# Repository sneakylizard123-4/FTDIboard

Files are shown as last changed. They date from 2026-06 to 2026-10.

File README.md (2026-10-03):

# FTDIboard

FTDIboard is a small USB-to-UART interface that uses the FT232RL and a switchable 3.3V/5V logic rail.

[Finished V1 board](proof/V1/image/IMG_20260908_173817_623.jpg)

---

## Key Features

- FT232RL USB-to-UART bridge
- Switchable 3.3V / 5V logic levels  
- ESP-style auto-reset
- USB ESD protection
- Resettable Fuse (PPTC): 600mA on VBUS 
- Fuse (not resettable): 2.5A fast fuse
- Lots of LEDs
- 75×50mm, 4-layer PCB
- M3 mounting holes
- 2.54mm standard headers

---

## Bill of Materials

| References | Qty | Value | Footprint |
|---|-----|---|---|
| U3 | 1 | FT232RL | SSOP-28 |
| U2 | 1 | TLV75733PDBV | SOT-23-5 |
| U1 | 1 | USBLC6-2SC6 | SOT-23-6 |
| C1 C4 C5 C7 C8 C10 | 6 | 100nF | 0805 |
| C6 C9 | 2 | 4.7uF | 0805 |
| C2 | 1 | 10uF | 0805 |
| C3 | 1 | 22uF | 0805 |
| R4 R10 R12 R13 R14 R15 R16 R17 R18 R19 R20 R21 R22 R23 R24 R25 | 16 | 10k | 0805 |
| R7 R8 R9 R11 | 4 | 1k | 0805 |
| R3 | 1 | 100k | 0805 |
| R1 R2 | 2 | 5.1k | 0805 |
| R5 R6 | 2 | 33R | 0805 |
| Q2 Q3 | 2 | BC817 | SOT-23 |
| Q1 | 1 | AO3401A | SOT-23 |
| D1 D2 D3 D4 D5 D6 D7 D8 D9 D10 D11 D12 D13 | 13 | LED | 0805 LED |
| J3 | 1 | Conn_01x04 | 1x4 Header 2.54mm |
| J2 | 1 | Conn_01x07 | 1x7 Header 2.54mm |
| J1 | 1 | USB_C_Receptacle_USB2.0_14P | USB-C Receptacle |
| F1 | 1 | 600mA hold, 1.2A trip | Disc 5.1mm |
| F2 | 1 | 2.5A trip | 0603 |
| SW1 | 1 | SW_SPDT_321 | SPDT Slide switch |

*Full BOM available in BOM.csv*

## Usage

1. Connect via USB
2. Install FTDI VCP drivers if needed
3. Select serial port in your IDE
4. Have fun

---

## Images

### PCB Layout
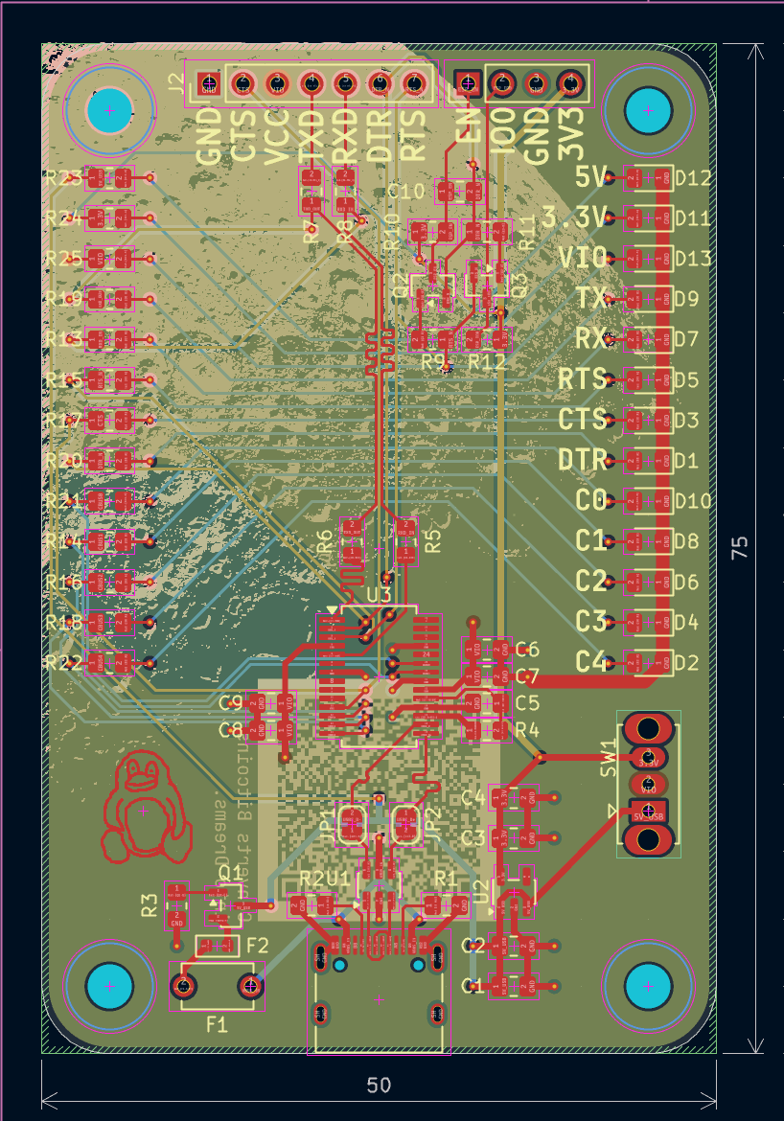
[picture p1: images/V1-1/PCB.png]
PCB


### Schematic
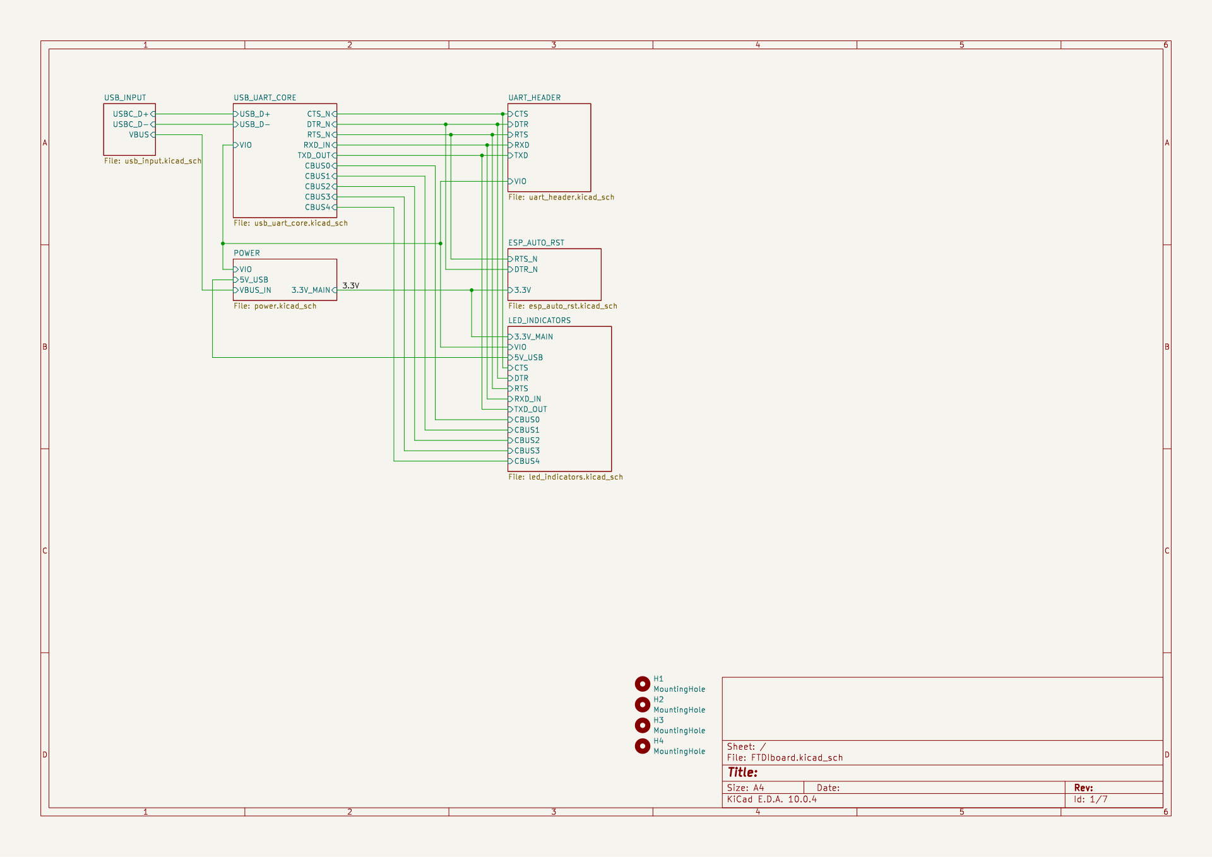
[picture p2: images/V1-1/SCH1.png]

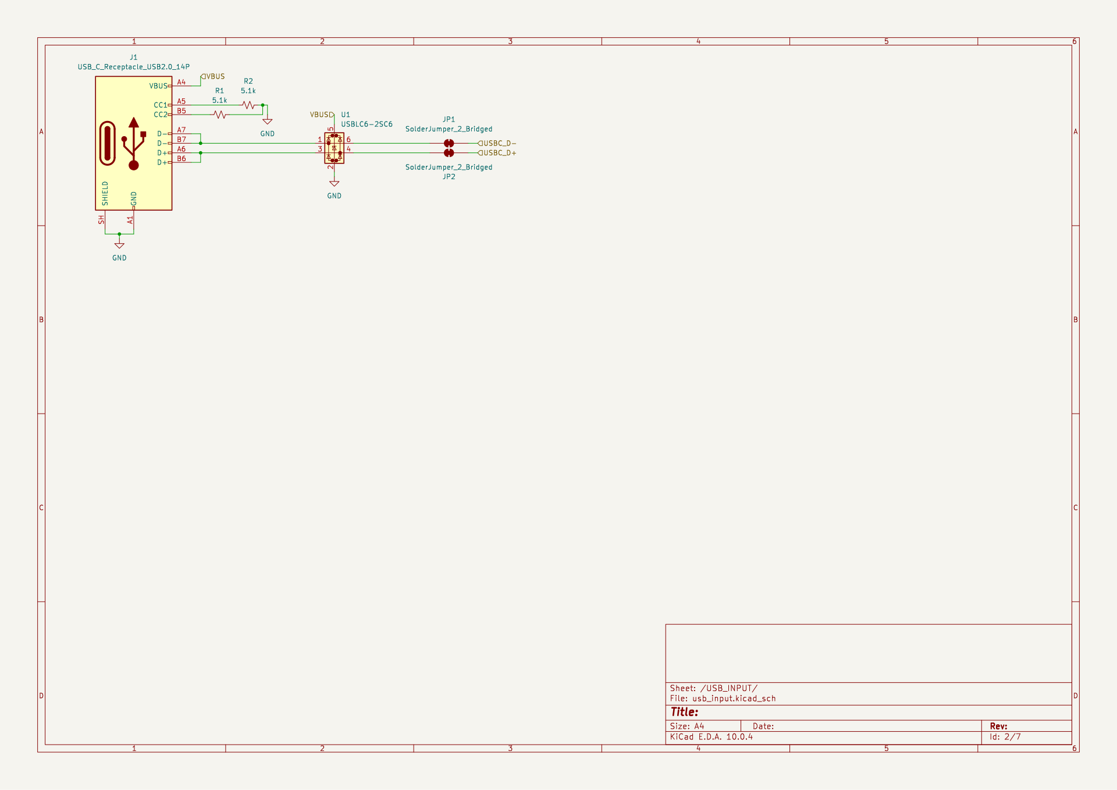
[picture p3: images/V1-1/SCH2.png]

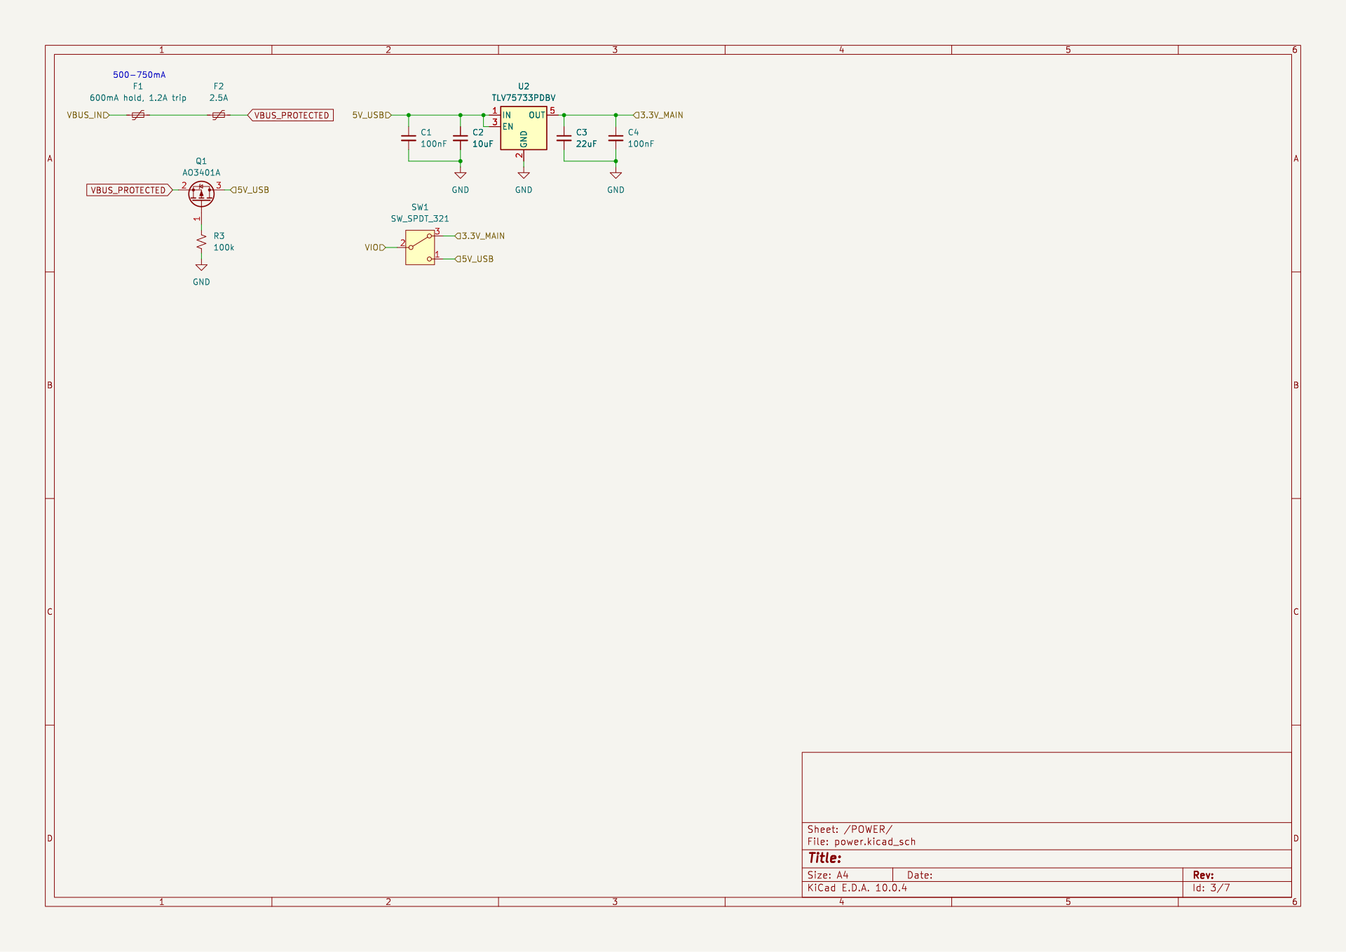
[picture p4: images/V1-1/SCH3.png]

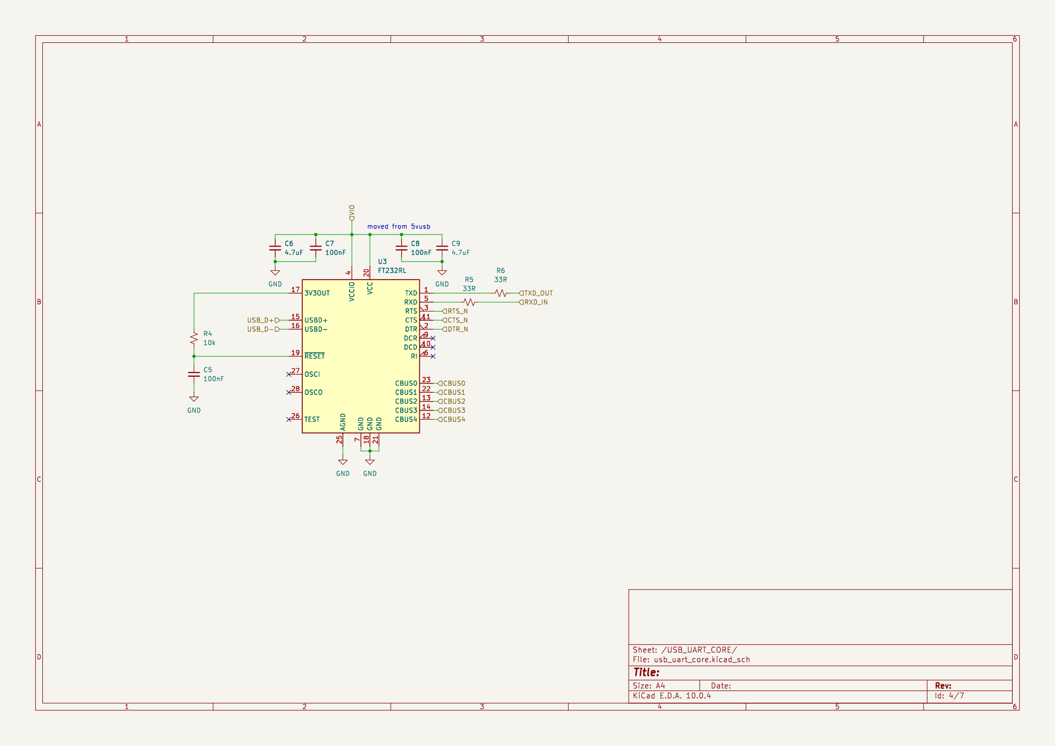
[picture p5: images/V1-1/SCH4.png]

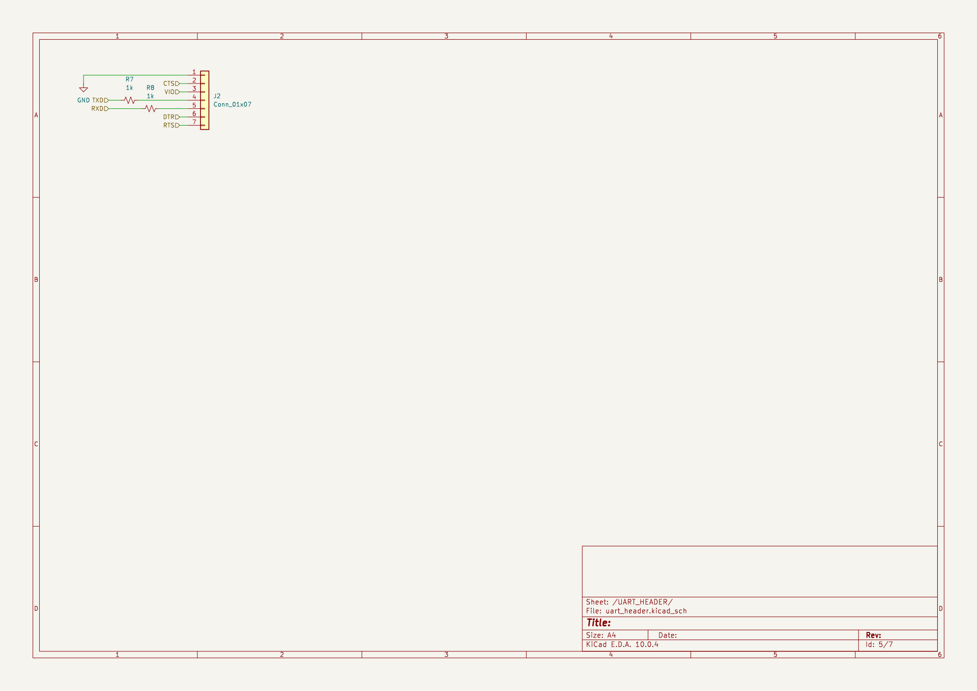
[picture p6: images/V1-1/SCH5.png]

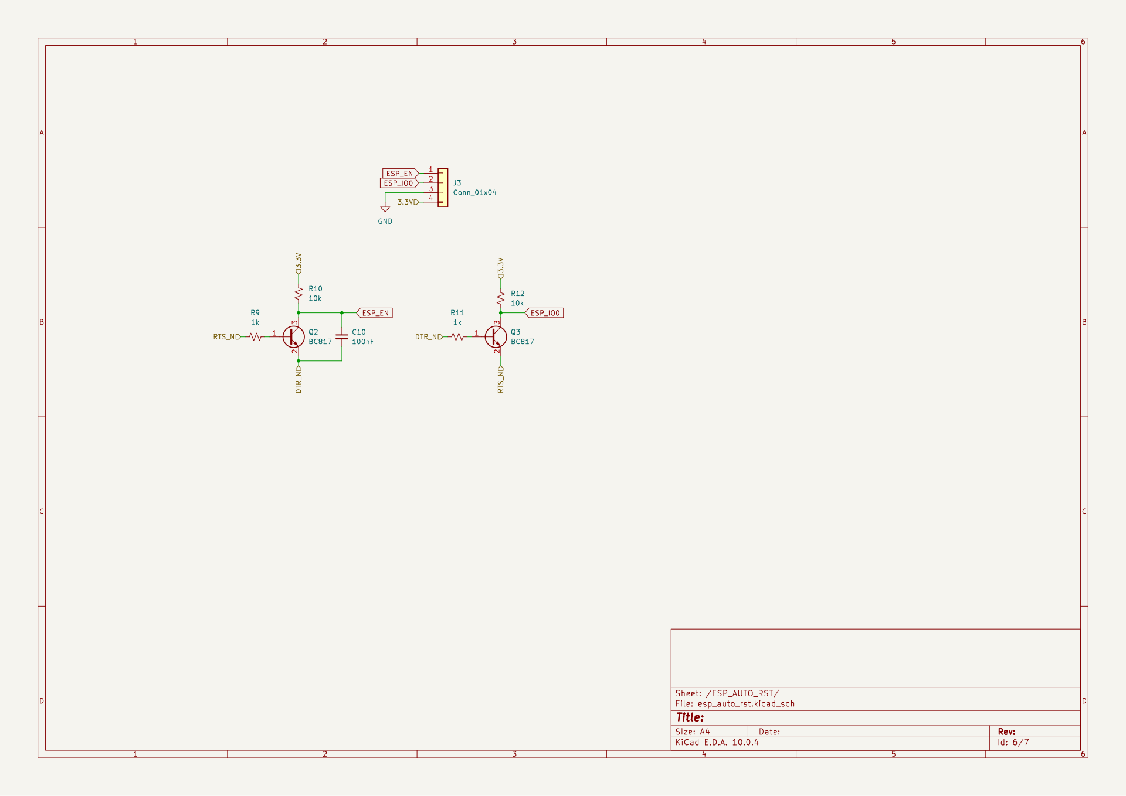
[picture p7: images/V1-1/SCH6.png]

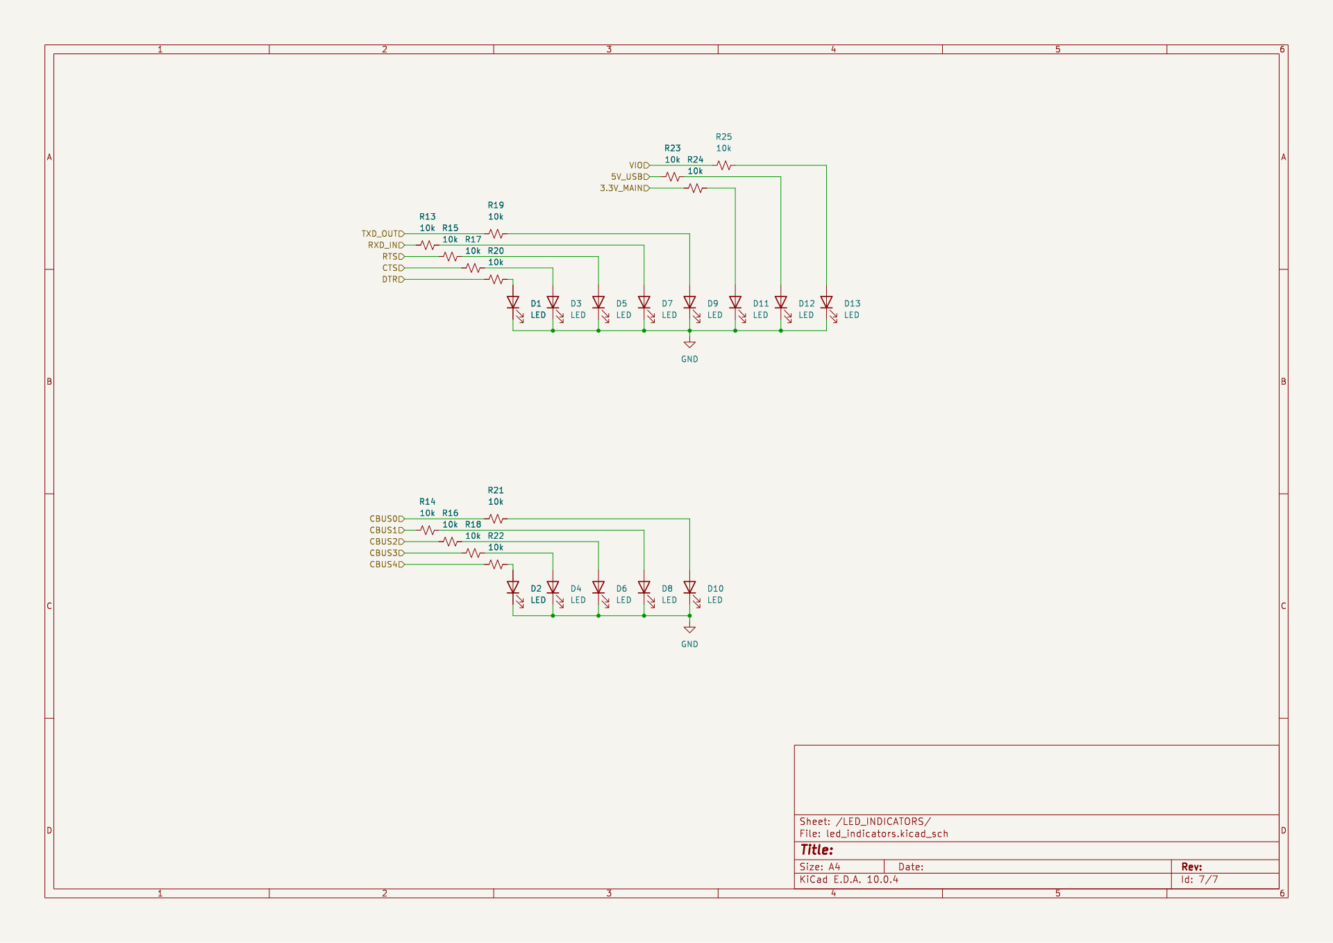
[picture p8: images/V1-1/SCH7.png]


### 3D Model
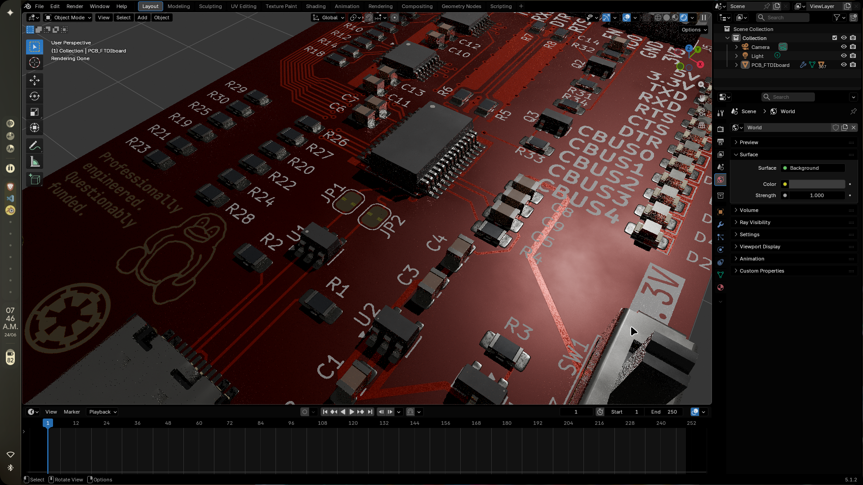
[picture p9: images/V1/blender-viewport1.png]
3D View

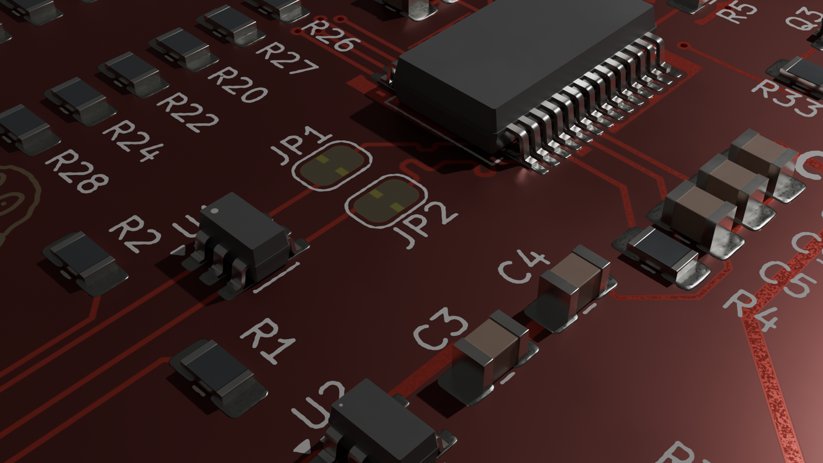
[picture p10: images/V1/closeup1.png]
Closeup


---

## Testing

v1.1 board built and tested, self-loopback passes clean. the two v1.0 bugbear fixes
(auto-reset latch, VCCIO following the switch) are confirmed gone in this revision.

- v1.1 build + test proof: `proof/V1-1/PROOF.md`
- v1.0 electrical soundness proof: `proof/V1/PROOF.md`

---

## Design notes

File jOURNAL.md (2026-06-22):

---
title: "FTDI Board"
author: pn2222a
descrriptioni: "FTDI USB board based on FT232RL chip"
created_at: "2026-06-21T02:59:14Z"
---

# June 20: finished board

finished the board.
added moon silkscreen and some more easter eggs, even though it will probably be only me that uses it
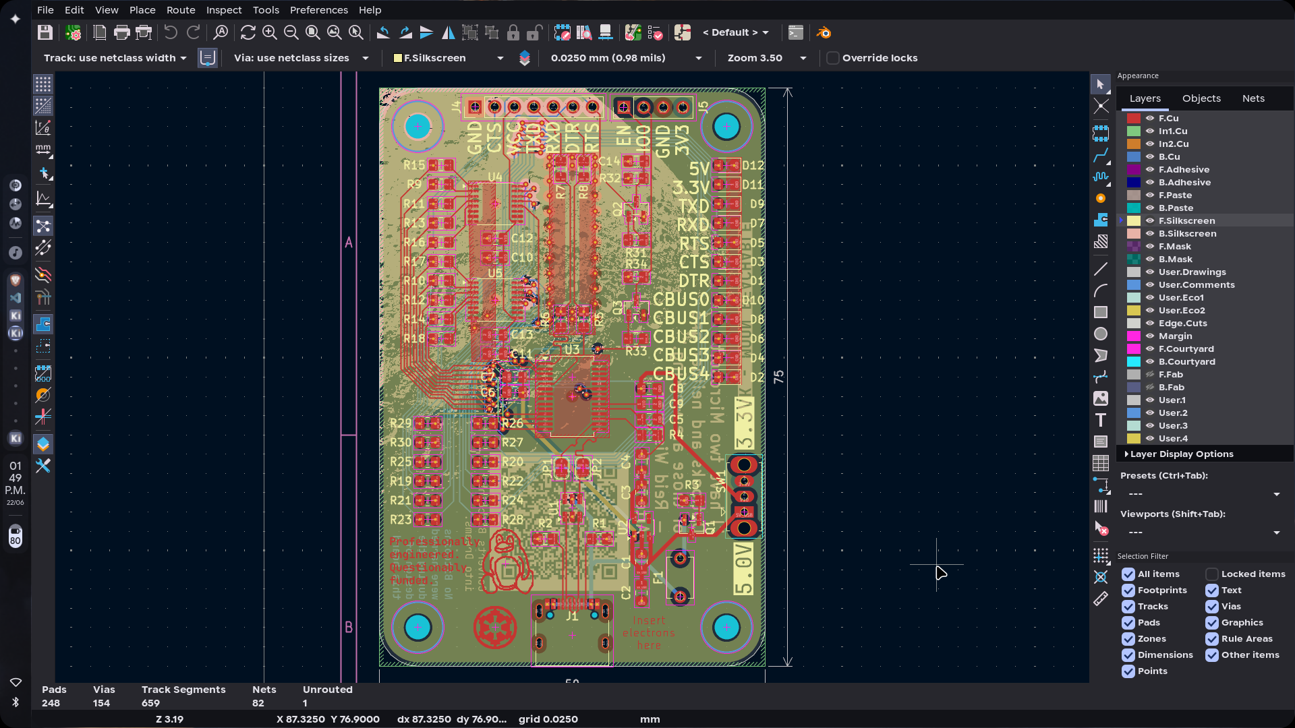
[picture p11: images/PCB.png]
pcb


**Total time spent: 6 hours**

# June 21: polishing repo
adding images from kicad and will start blendering soon for some cool renders
i need to learn how to make the renders faster.
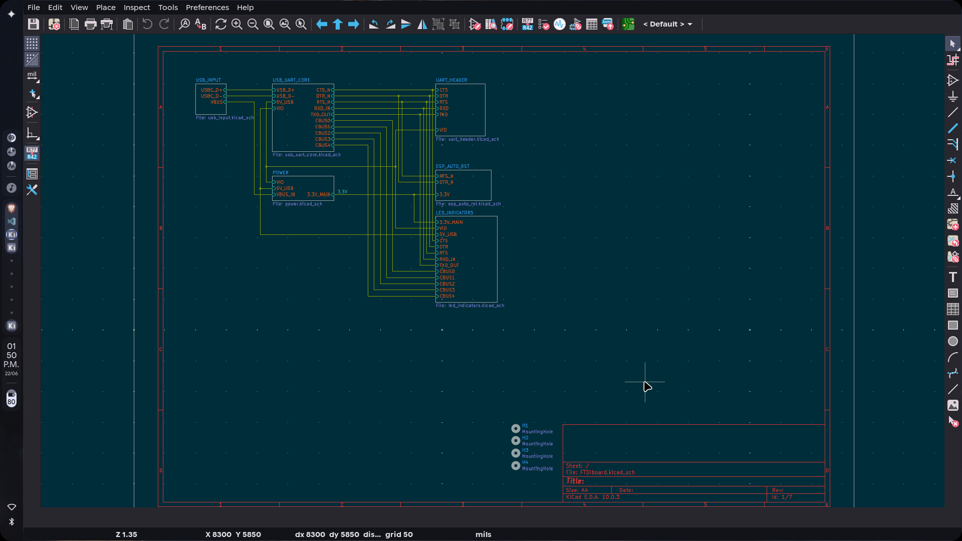
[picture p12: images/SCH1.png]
sch


**Total time spent: 2 hours**

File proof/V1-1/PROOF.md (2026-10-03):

# v1.1 Build + Testing Proof

Build/test date: September 21, 2026. This is the v1.1 revision (no ULN2003s, second
fuse, 13 LEDs, full reroute from the September 1 redesign).

## Build

- PCBs assembled, powered up, nothing released the magic smoke.
- Fuse footprint bridged with tweezers (same as v1.0 - never bothered fitting
  the PPTC, just shorted it). On camera: `video/VID_20260921_184839.mp4`.
- All LEDs lit and stayed lit.

## Testing

- Re-ran the proof kit from v1.0 (self-loopback, paced ESP32 traffic,
  sustained-load stress).
- The two v1.0 issues are gone in this revision:
  - auto-reset stage no longer latches (was a bodge wire on v1.0)
  - VCCIO rail follows the switch properly, no bodge wire needed (was 3.3V
    even in 5V mode on v1.0)
- Test script running on camera: `video/VID_20260921_190001.mp4`.
- Full self-loopback passes clean.

## Media

| File | What it shows |
|---|---|
| `video/VID_20260921_184839.mp4` | bridging the fuse with tweezers, LEDs lighting up |
| `video/VID_20260921_190001.mp4` | test script running / self-loopback passing |
| `image/IMG_20260921_185508_130.jpg` | built v1.1 board |
| `image/IMG_20260921_185721_778.jpg` | built v1.1 board |

See `proof/V1/PROOF.md` for the original v1.0 electrical soundness proof.

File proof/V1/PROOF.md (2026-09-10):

# Custom FT232RL Board - Interconnection Proof

Date of test: September 2, 2026 - All tests on `/dev/ttyUSB0` (custom board, bus 3-1, id `0403:6001`)

## Bottom line
The custom FT232RL USB-UART board is **electrically sound** (Yay!). Intermittent bit flips seen in
sustained transfers to the ESP32 are caused by a **marginal hookup wire / connection on the
board->ESP32 path, not by the board** and not by the ESP32.

---

## 1. Board integrity - pure self-loopback (decisive)
Board TX jumpered to RX, ESP32 fully disconnected.

- 500 x 512-byte pseudo-random blocks @ 115200 baud, back-to-back
- **Result: 500/500 PASS, 0 bad bytes, 8.7 kB/s**

```
=== SELF-LOOPBACK RESULT ===
passed : 500/500
failed : 0
bad bytes total: 0
VERDICT: PASS - BOARD TX/RX DRIVER INTEGRITY OK
```
Script: `board_selfloopback.py`

512 bytes was chosen because it is the exact block size that triggers bit flips *through the
ESP32*; the board alone never flips a bit. This rules out the board's TX/RX driver.

## 2. Direct PC loopback (board + cable + PC port all proven)
Board TX/RX jumpered, driven purely by the host PC.

- 100 x 32-byte pseudo-random chunks @ 115200
- **Result: 100/100 echoed correctly, 0 errors**

## 3. Integration with ESP32 (Adafruit HUZZAH32, UART2 RX=19/TX=21)
- Light traffic (16-byte frames, 50 ms gap): **20/20 PASS**
- Short frames (<=64 B, even 100 uss gap): **100% PASS**
- Single bytes: **300/300 PASS**

The board reliably talks to the ESP32 for normal, paced UART traffic.

## 4. The fault we chased (for completeness)
Under sustained ~512-byte back-to-back frames to the ESP32, ~40% of blocks had **exactly one
bad byte with 1-2 single-bit flips** (no frameshift, no desync - e.g. `0x47->0x07`). Downstream
checks proved:
- Not an ESP32 buffer overflow (enlarged RX buffer -> no change).
- Corruption originates on the **board TX -> ESP RX wire**, since the ESP32 mirrored exactly what
  arrived (board echo and ESP mirror were always bad together).
- The board alone does not produce it (see sec.1).

So the flips exist only when the board drives the wire to the ESP32 -> **marginal hookup wire /
contact**, consistent with the earlier-measured ~12 ohm twisted pair.

## Media

Videos from GoPro camera. Originals are 4-5K and several GB
each, so the repo only contains compressed 1280px or 960px previews in `video/compressed/`.

## Files
- Board self-loopback proof: `board_selfloopback.py`
- 1 MB stress benchmark: `customboard_bench.py` (fails via wire, see sec.4)
- Diagnostics: `diag_rate.py`, `diag_txrx.py`, `diag_bits.py`
- ESP32 echo firmware: `esp32_echo` (UART2 RX=19/TX=21, echoes + mirrors to UART0)

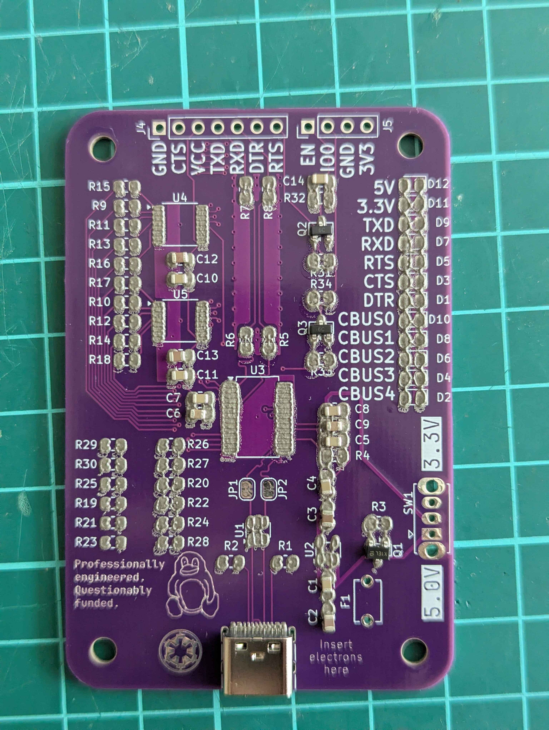
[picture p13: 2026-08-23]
images/V1/paste_5.jpg

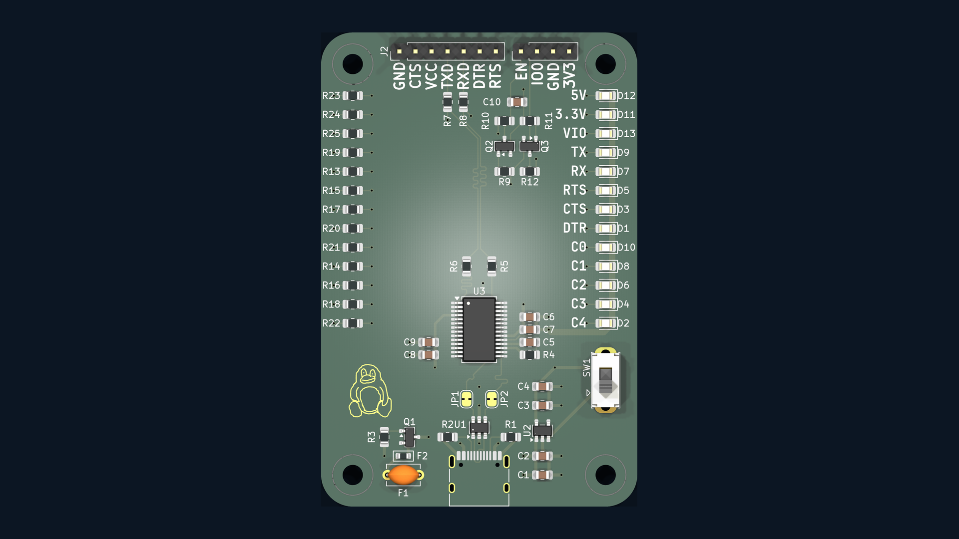
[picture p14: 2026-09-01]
images/V1-1/PCB-Render.png

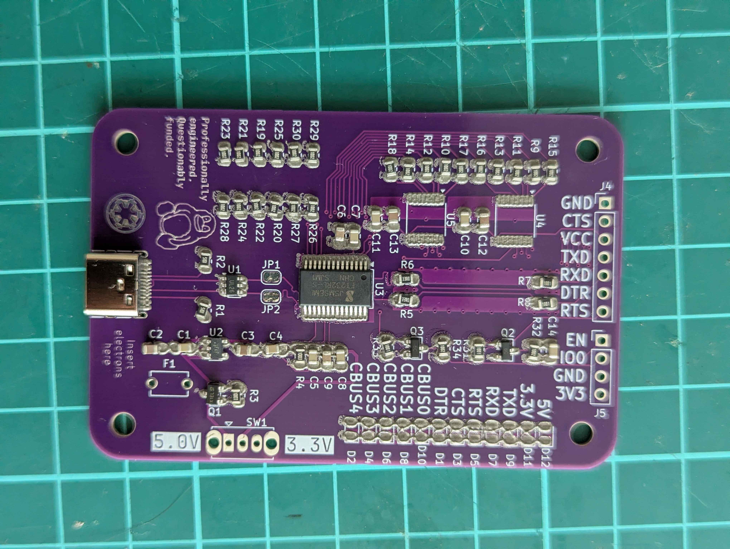
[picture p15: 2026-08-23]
images/V1/paste_10.jpg

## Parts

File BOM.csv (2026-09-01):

Component | Qty | LCSC Part # | Unit Price | Line Total | Buy
FT232RL | 1 | C8690 | $6.1561 | $6.16 | https://www.lcsc.com/product-detail/_C8690.html
TLV75733PDBV | 1 | C485517 | $0.1819 | $0.18 | https://www.lcsc.com/product-detail/_C485517.html
USBLC6-2SC6 | 1 | C7519 | $0.0896 | $0.09 | https://www.lcsc.com/product-detail/_C7519.html
100nF 0805 | 6 | C1711 | $0.0266 | $0.16 | https://www.lcsc.com/product-detail/_C1711.html
4.7uF 0805 | 2 | C98195 | $0.0450 | $0.09 | https://www.lcsc.com/product-detail/_C98195.html
10uF 0805 | 1 | C15850 | $0.2211 | $0.22 | https://www.lcsc.com/product-detail/_C15850.html
22uF 0805 | 1 | C907991 | $0.1794 | $0.18 | https://www.lcsc.com/product-detail/_C907991.html
10k 0805 | 16 | C2889526 | $0.0009 | $0.01 | https://www.lcsc.com/product-detail/_C2889526.html
1k 0805 | 4 | C2907232 | $0.0033 | $0.01 | https://www.lcsc.com/product-detail/_C2907232.html
100k 0805 | 1 | C100049 | $0.0038 | $0.00 | https://www.lcsc.com/product-detail/_C100049.html
5.1k 0805 | 2 | C27834 | $0.0035 | $0.01 | https://www.lcsc.com/product-detail/_C27834.html
33R 0805 | 2 | C2907258 | $0.0031 | $0.01 | https://www.lcsc.com/product-detail/_C2907258.html
BC817 SOT-23 | 2 | C22400355 | $0.0110 | $0.02 | https://www.lcsc.com/product-detail/_C22400355.html
AO3401A SOT-23 | 1 | C15127 | $0.0717 | $0.07 | https://www.lcsc.com/product-detail/_C15127.html
LED Green 0805 | 2 | C2297 | $0.0163 | $0.03 | https://www.lcsc.com/product-detail/_C2297.html
LED Yellow 0805 | 1 | C2296 | $0.0123 | $0.01 | https://www.lcsc.com/product-detail/_C2296.html
LED Blue 0805 | 1 | C2293 | $0.0123 | $0.01 | https://www.lcsc.com/product-detail/_C2293.html
LED Orange 0805 | 2 | C110371 | $0.0159 | $0.03 | https://www.lcsc.com/product-detail/_C110371.html
LED Red 0805 | 1 | C2295 | $0.0116 | $0.01 | https://www.lcsc.com/product-detail/_C2295.html
LED White 0805 | 6 | C34499 | $0.0203 | $0.12 | https://www.lcsc.com/product-detail/_C34499.html
Conn_01x04 2.54mm | 1 | C41427519 | $0.2015 | $0.20 | https://www.lcsc.com/product-detail/_C41427519.html
Conn_01x07 2.54mm | 1 | C22438157 | $0.1192 | $0.12 | https://www.lcsc.com/product-detail/_C22438157.html
USB-C Receptacle 14P | 1 | C165948 | $0.1857 | $0.19 | https://www.lcsc.com/product-detail/_C165948.html
PPTC 600mA/1.2A | 1 | C94464 | $0.2491 | $0.25 | https://www.lcsc.com/product-detail/_C94464.html
Polyfuse 2.5A 0603 | 1 | C207017 | $0.2652 | $0.27 | https://www.lcsc.com/product-detail/_C207017.html
SPDT Slide Switch | 1 | C221829 | $0.6162 | $0.62 | https://www.lcsc.com/product-detail/_C221829.html
PCB | 1 |  | $20.0000 | $20.00 | https://www.jlcpcb.com/
STENCIL | 1 |  | $15.0000 | $15.00 | https://www.jlcpcb.com/
 |  |  |  |  | COMPONENT TOTAL: $9.07
 |  |  |  |  | PCB TOTAL: $35.00
 |  |  |  |  | TOTAL: $44.07

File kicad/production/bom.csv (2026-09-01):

Designator | Footprint | Quantity | Value | LCSC Part #
C1, C10, C4, C5, C7, C8 | 0805 | 6 | 100nF
C2 | 0805 | 1 | 10uF
C3 | 0805 | 1 | 22uF
C6, C9 | 0805 | 2 | 4.7uF
D1, D10, D11, D12, D13, D2, D3, D4, D5, D6, D7, D8, D9 | 0805 | 13 | LED
F1 | C_Disc_D5.1mm_W3.2mm_P5.00mm | 1 | 600mA hold, 1.2A trip
F2 | 0603 | 1 | 2.5A
J1 | USB_C_Receptacle_HRO_TYPE-C-31-M-12 | 1 | USB_C_Receptacle_USB2.0_14P
J2 | PinHeader_1x07_P2.54mm_Vertical | 1 | Conn_01x07
J3 | PinHeader_1x04_P2.54mm_Vertical | 1 | Conn_01x04
Q1 | SOT-23 | 1 | AO3401A
Q2, Q3 | SOT-23 | 2 | BC817
R1, R2 | 0805 | 2 | 5.1k
R10, R12, R13, R14, R15, R16, R17, R18, R19, R20, R21, R22, R23, R24, R25, R4 | 0805 | 16 | 10k
R11, R7, R8, R9 | 0805 | 4 | 1k
R3 | 0805 | 1 | 100k
R5, R6 | 0805 | 2 | 33R
SW1 | SW_Slide_SPDT_Straight_CK_OS102011MS2Q | 1 | SW_SPDT_321
U1 | SOT-23-6 | 1 | USBLC6-2SC6
U2 | SOT-23-5 | 1 | TLV75733PDBV
U3 | SSOP-28_5.3x10.2mm_P0.65mm | 1 | FT232RL

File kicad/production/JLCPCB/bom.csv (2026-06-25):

Designator | Footprint | Quantity | Value | LCSC Part #
C1, C10, C11, C14, C4, C5, C7, C8 | 0805 | 8 | 100nF
C12, C13, C2 | 0805 | 3 | 10uF
C3 | 0805 | 1 | 22uF
C6, C9 | 0805 | 2 | 4.7uF
D1, D10, D11, D12, D2, D3, D4, D5, D6, D7, D8, D9 | 0805 | 12 | LED
F1 | C_Disc_D5.1mm_W3.2mm_P5.00mm | 1 | 600mA hold, 1.2A trip
J1 | USB_C_Receptacle_HRO_TYPE-C-31-M-12 | 1 | USB_C_Receptacle_USB2.0_14P
J4 | PinHeader_1x07_P2.54mm_Vertical | 1 | Conn_01x07
J5 | PinHeader_1x04_P2.54mm_Vertical | 1 | Conn_01x04
Q1 | SOT-23 | 1 | AO3401A
Q2, Q3 | SOT-23 | 2 | BC817
R1, R2 | 0805 | 2 | 5.1k
R10, R11, R12, R13, R14, R15, R16, R17, R18, R19, R20, R21, R22, R23, R24, R25, R26, R27, R28, R29, R30, R32, R34, R4, R9 | 0805 | 25 | 10k
R3 | 0805 | 1 | 100k
R31, R33, R7, R8 | 0805 | 4 | 1k
R5, R6 | 0805 | 2 | 33R
SW1 | SW_Slide_SPDT_Straight_CK_OS102011MS2Q | 1 | SW_SPDT_321
U1 | SOT-23-6 | 1 | USBLC6-2SC6
U2 | SOT-23-5 | 1 | TLV75733PDBV
U3 | SSOP-28_5.3x10.2mm_P0.65mm | 1 | FT232RL
U4, U5 | TSSOP-16_4.4x5mm_P0.65mm | 2 | ULN2003

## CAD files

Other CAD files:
blender/FTDIboard.blend

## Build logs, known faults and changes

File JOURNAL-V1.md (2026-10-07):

---
title: "FTDI Board"
author: pn2222a
description: "FTDI USB board based on FT232RL chip"
created_at: "2026-06-21T02:59:14Z"
---

# June 10: project start and component selection

started the project. wanted to build a usb-to-uart board for flashing esp32 and other mcus, got tired of using ones where i cant see the insides. the lab ones are always either broken or being used by someone else anyway.

spent a while on the ic. ft232rl is old but its cheap and everyone has docs on it. looked at cp2102 too but the ft232rl has more cbus pins and full flow control so it wins for debugging. probably should have checked if its end of life yet but whatever, its everywhere so itll be fine.

picked tlv75733 for 3.3v because i have lots lying around, switchable to 5v for the output. usblc6 for esd on the data lines. pptc fuse on the input because im clumsy and i dont want to fry a laptop usb port. usb-c because its 2026, but i had a lot of those lying around too.

wrote out the whole passive list too - 25x 10k, 4x 1k, a 100k, 2x 5.1k, 2x 33r, and the caps. all 0805 because i dont hate myself. made the kicad project skeleton.

sch power

**Total time spent: 2 hours**

# June 11: schematic - power section

did the power section first.

usb-c with two 5.1k cc pulldowns so it acts as a device. took forever to get the orientation and cc1/cc2 wiring right, and figuring out which pins to tie for usb2.0. kept second guessing whether i needed the shield connected to gnd or through a resistor.

esd protection with usblc6 between d+/d- and gnd. 33r series on each data line, sized the caps so the impedance stays in usb2.0 range. the differential impedance math took me a few tries but i think ive got it close enough, usb2.0 is forgiving. if it doesnt work i can use different parts

pptc on vbus with a 100nf right at the connector. ldo with 10uf in and out, plus a 4.7uf further down the rail. the slide switch picks between 3.3v and 5v.

tricky bit was making sure the switch cant back-feed the regulator and short vbus to gnd. ended up putting the mosfet in the load path to stop that. not sure if its overkill but its cheap and it works.

sch power

**Total time spent: 3 hours**

# June 13: schematic - ft232rl core

added the ft232rl.

crystal-less, it has an internal clock, saved a bunch of space and a couple of parts. checked the osc settings work at both 3.3v and 5v. honestly glad i dont have to mess with crystal load caps, those always trip me up.

decoupling caps on every power pin, right values on the internal reg output. went through the datasheet pin by pin so nothing floats - pulled the unused ones to a known state. the datasheet pdf is ancient but at least its thorough.

hooked the status pins (txd rxd rts cts dtr dsr dcd ri) to the led network.

then the esp auto-reset circuit with the two bc817s on dtr/rts. this was the worst part. the ide toggles dtr/rts to enter bootloader and the transistors have to pull esp enable and gpio0 at the right times. spent ages getting the polarity right so the reset sequence matches what esptool wants, 100k pullup on reset so it sits high by default. i read like three different forum posts about this before it clicked (wonderous foreshadowing here).

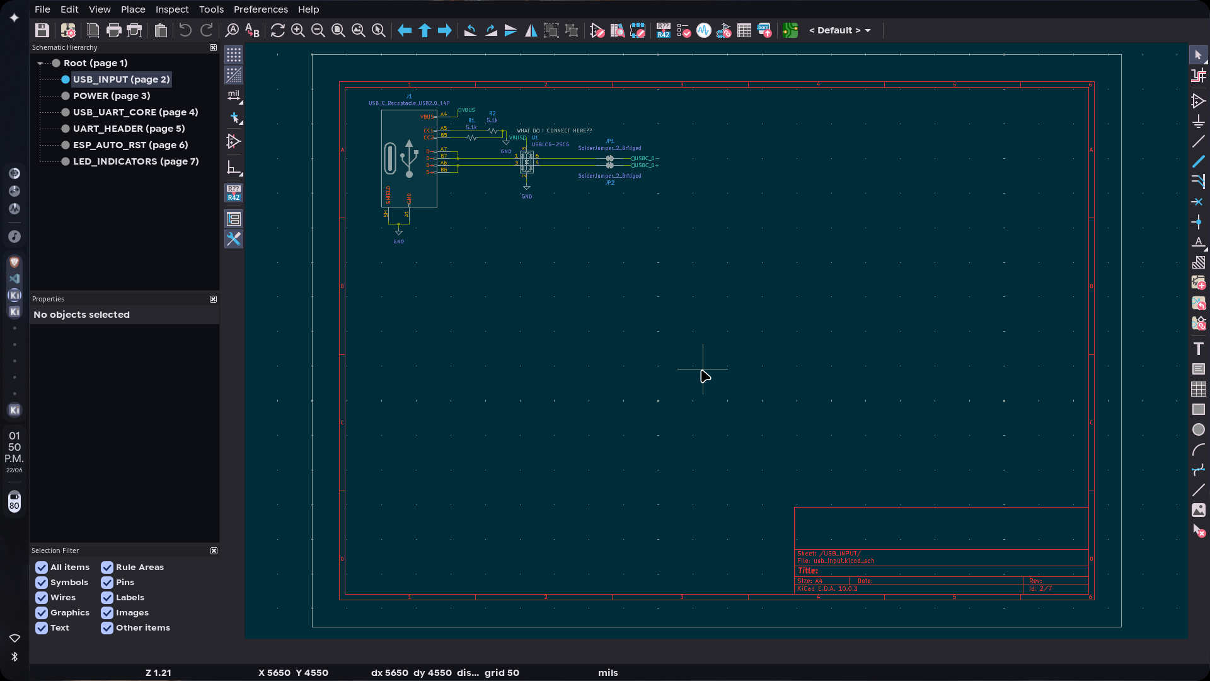
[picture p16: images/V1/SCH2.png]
sch core


**Total time spent: 4 hours**

# June 14: schematic - leds and connectors

finished the leds. 12 of them. 2 green for power, yellow for tx, blue for rx, 2 orange for flow control, red for dtr, 5 white for cbus. probably way more than i need but i like seeing what the chip is doing at a glance, plus leds=fun.

each one gets a 1k series resistor so they run at like 2-3ma. had to redo the values per color since red/blue/green/yellow/white all have different forward voltages. the blues and whites are annoyingly bright even at low current so i might dial those back later.

added the headers - 1x7 for uart, 1x4 for extra cbus/gpio. everything 0805 so i can hand solder it. i hate soldering anything smaller than 0805, did enough of that in the lab already.

also put in two uln2003s to buffer the cbus outputs, open-collector so i can switch bigger stuff than leds later. honestly not sure i need them but theyre cheap insurance.

did the full review at the end, ran erc. caught two nets that were the same signal with different names and a polarity error on a transistor. fixed em, erc is clean now. saved a real headache down the line with those net names, board house would have probably rejected it.

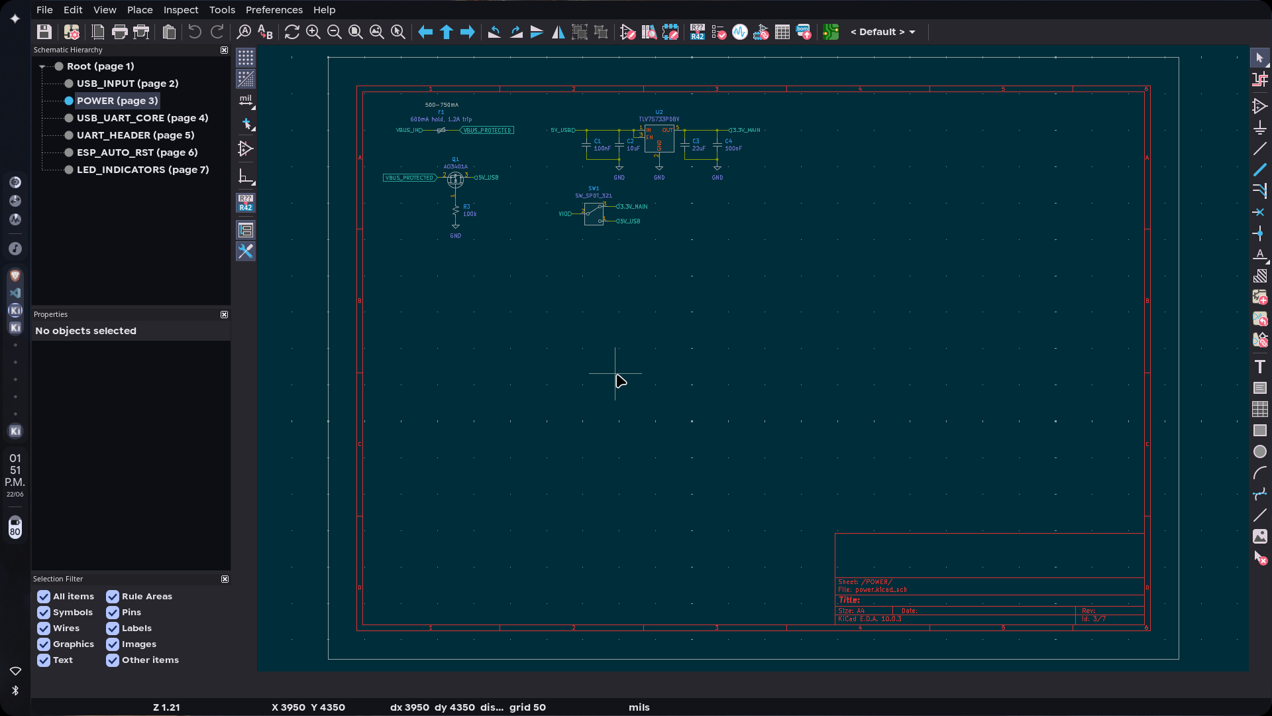
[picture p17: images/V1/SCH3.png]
sch leds


**Total time spent: 3 hours**

# June 16: initial pcb layout

imported the netlist and started placing.

usb connector on one edge, headers on the opposite so it sits nice on a breadboard. ft232rl in the middle with bypass caps shoved right against its power pins. i kept the caps within a couple mm of the pins, that whole "0.1uf as close as possible" thing is real.

led resistors next to their leds to keep the fan-out clean. power stuff (ldo switch mosfet) in a corner so the switching noise stays away from usb. also rotated the silkscreens around so the labels wouldnt be upside down, small thing but it bugs me.

75x50mm with m3 holes in the corners, fits a case. went 4-layer - signal/gnd/power/signal - makes routing way easier. costs a bit more per board but whatever, this is a one off.

moved components around a lot until the ratsnest crossings were low and the usb path to the ft232rl was short. placement is everything, bad placement ruins the routing later.

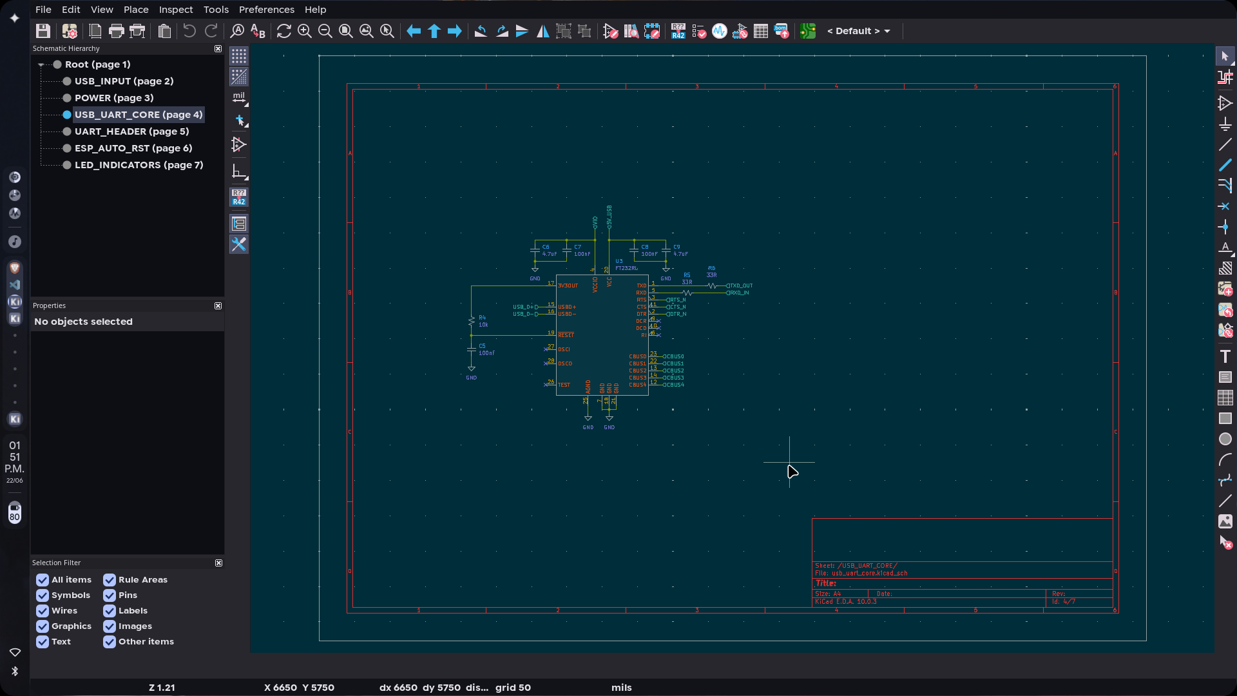
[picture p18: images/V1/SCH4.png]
pcb placement


**Total time spent: 4 hours**

# June 17: pcb routing

started routing. 0.5mm power traces, 0.2mm signals, 0.2mm clearance. probably fine for the currents here, the leds barely draw anything.

inner layers are the gnd and 3.3v planes so the outer layers stay free for signals. this is why 4-layer is nice, i barely had to think about return paths, there's a plane under everything. no ground loops to worry about on a board this small anyway.

did the usb differential pair first since its the critical one. kept d+/d- together and length matched, series resistors inline, no vias in the pair. matched them to within like a mm which is way better than usb2.0 needs.

set up the planes with thermal reliefs so soldering isnt a nightmare of heat sinking. first board i forgot those and the whole plane was a heatsink, never again.

then fanned the ft232rl out - status pins to their leds and resistors, power rails to the planes.

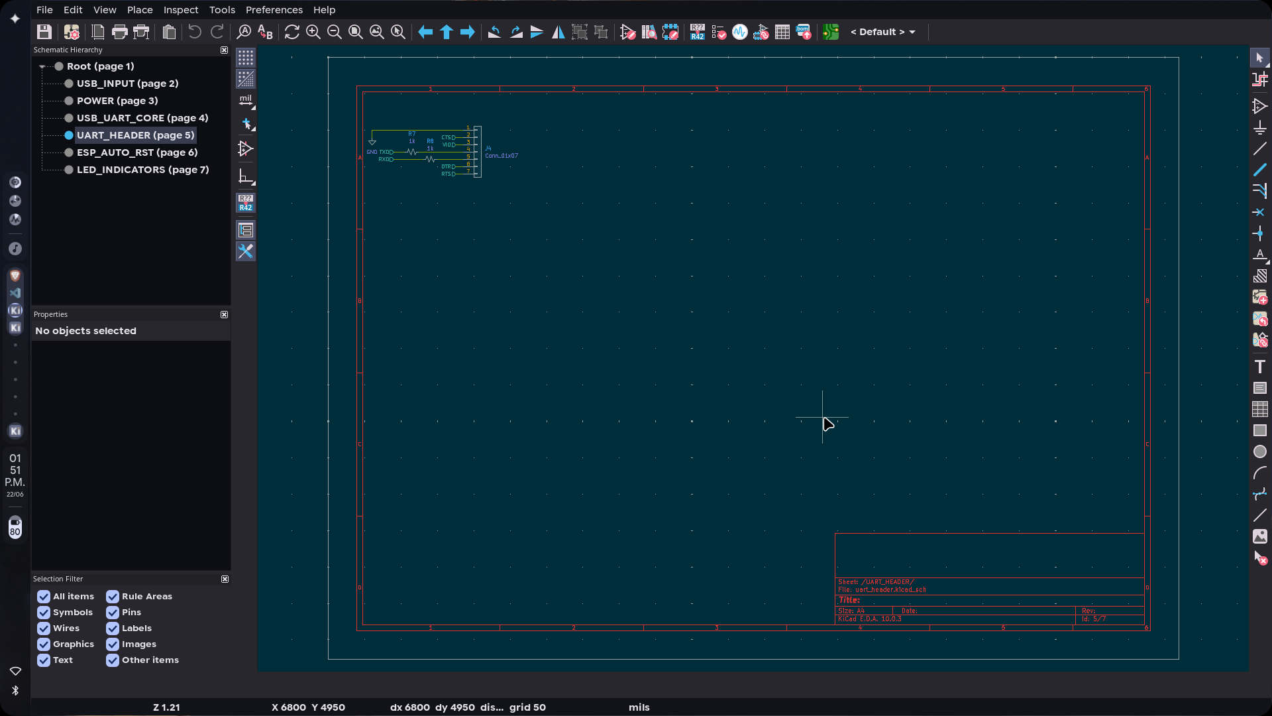
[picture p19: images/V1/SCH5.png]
pcb routing


**Total time spent: 5 hours**

# June 18: pcb routing continued

finished the rest - auto-reset circuit, cbus buffering, header connections. the auto-reset transistors got shoved in a corner with their resistors which is a bit cramped but it fits.

got all the leds routed through their resistors as a clean fan-out from the status pins. tried to keep the led traces grouped by color so the board looks organized.

thermal reliefs on the plane connections, 33r usb resistors as close to the connector as i could get them.

drc flagged a few clearance violations near the usb connector where the cc resistors and esd were fighting for space. fixed those, and some ugly via fanout angles. widened a couple power traces after adding up the led current, 0.5mm was honestly fine but 0.7mm feels safer.

cleaned up the rest - killed unnecessary vias, straightened traces so it doesnt look like spaghetti. this always takes longer than i expect, its the fiddly part of routing.

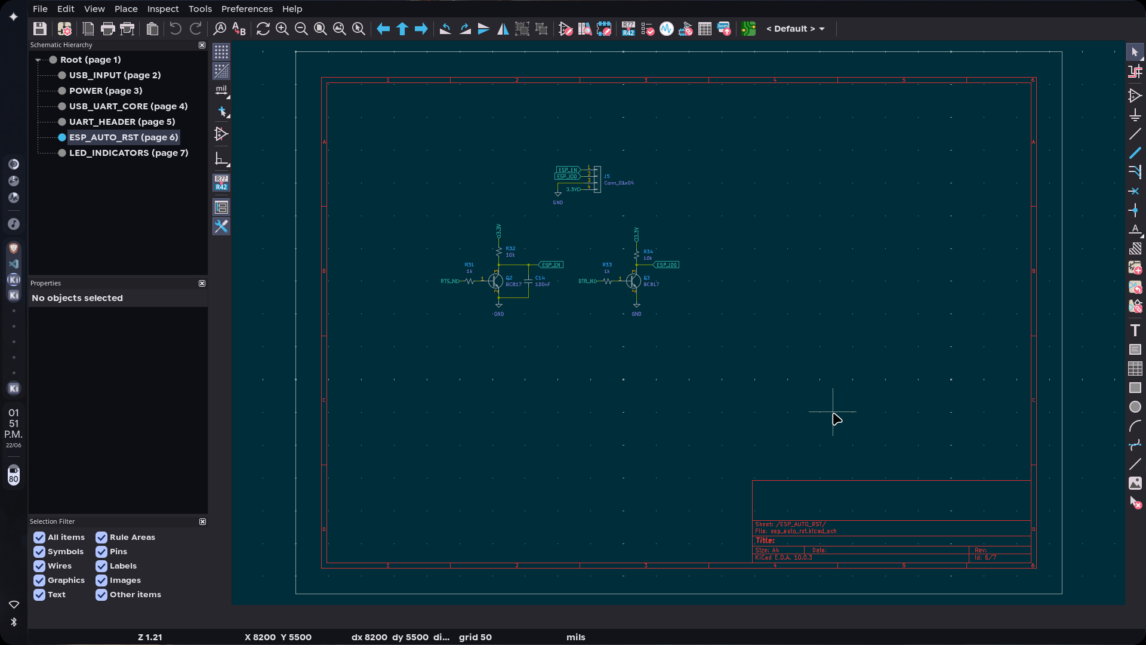
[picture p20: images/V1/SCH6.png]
pcb routing2


**Total time spent: 4 hours**

# June 19: final pcb touches

silkscreen labels on everything. connectors, switch positions (3.3v/5v), led polarity, reference designators where you can actually read them. left enough space around the labels so they dont get wiped out by the mask.

project name and version on the board, small maker mark.

added a moon on the silkscreen as an easter egg. took a while to get the graphic converted so it wouldnt overlap pads or courtyards. traced it in inkscape first because i couldnt find a good image to import.

final drc across everything - clearance, silkscreen to pad, courtyard overlaps, unconnected nets. all passed. honestly thought thered be something but it was clean first try.

exported gerbers and checked em in the previewer so nothing was flipped or missing. drill file looks right too.

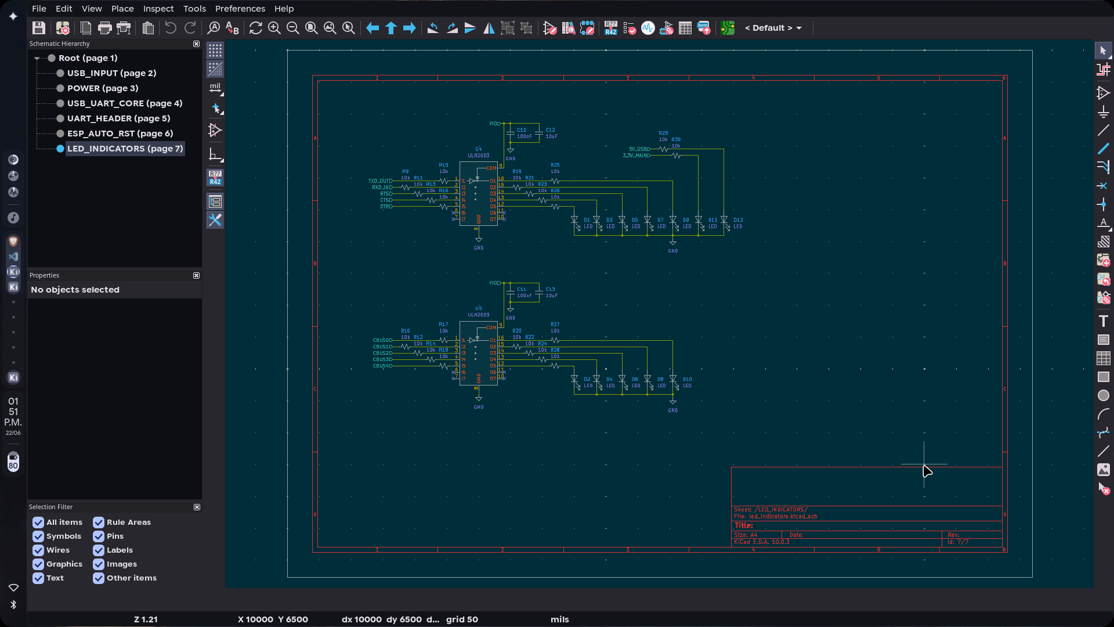
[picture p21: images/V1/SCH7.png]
pcb final


**Total time spent: 3 hours**

# June 20: finished board

finished the board.

added more easter eggs - a tiny rocket next to the moon, and a smiley on the back. probably only me that ever uses this but the details make it fun. noticed the smiley and the rocket kind of tell a story which is neat.

checked the ft232rl footprint against the datasheet pin spacing again, usb connector pins line up, mounting holes clear everything. printed it out at 1:1 on paper just to eyeball the component sizes and make sure nothing felt impossibly small.

exported the final fab files - gerbers, drills, pick and place. last look in the 3d viewer. went back and forth on the solder mask color for like an hour before ordering, ended up purple.

pcb

**Total time spent: 6 hours**

# June 21: polishing repo
adding images from kicad and will start blendering soon for some cool renders
i need to learn how to make the renders faster.
spent a bunch of the time just exporting screenshots from kicad and cropping them so they dont look terrible in the readme.
sch

**Total time spent: 2 hours**

# June 23: Blender
started blender model for pcb
red solder mask, white silkscreen, enig finish
set up a few test renders to get the lighting right, the board keeps coming out too dark or too shiny, still fiddling with it
render

**Total time spent: 3 hours**

# June 24: polish readme
adding images to readme and make bom.csv draft for parts and whatnot
will make more blender renders soon with animations and effects
also played around with a turntable animation idea for the board, not sure if i'll commit to it yet
sch

**Total time spent: 3 hours**

# June 25: BOM
looked for parts and made a bom
parts are from lcsc
added pcbs from jlcpcb and pcbway just in case
the more the merrier they say
took a while going through every single resistor and cap to find the right lcsc part number, stock kept running out on the cheap ones
sch

**Total time spent: 4 hours**

# August 22: boards arrived, soldering

pcbs finally showed up. purple mask looks even better in person than the renders.
decided to try paste this time instead of soldering every pad by hand. spread it on with a stencil-ish approach, took a bunch of progress shots because it was weirdly satisfying.

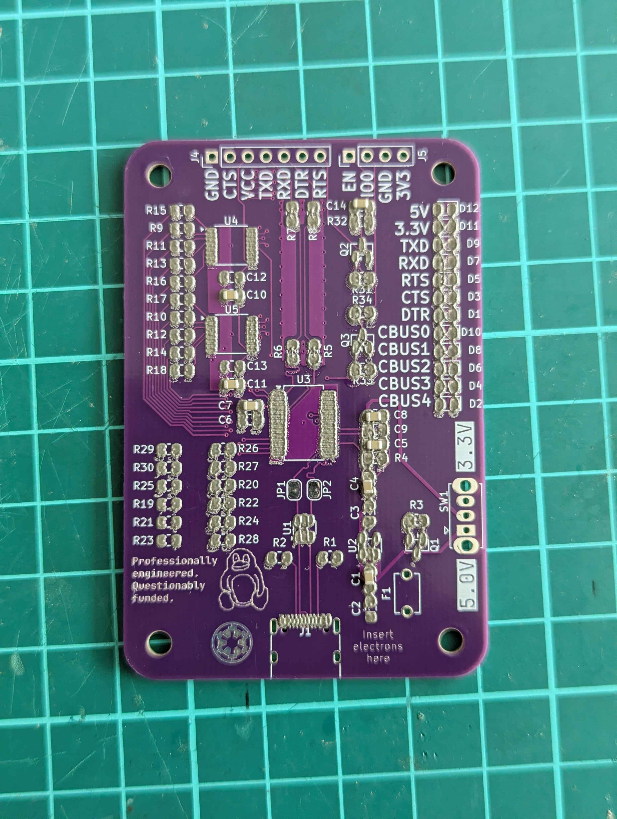
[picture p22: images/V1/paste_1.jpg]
paste start

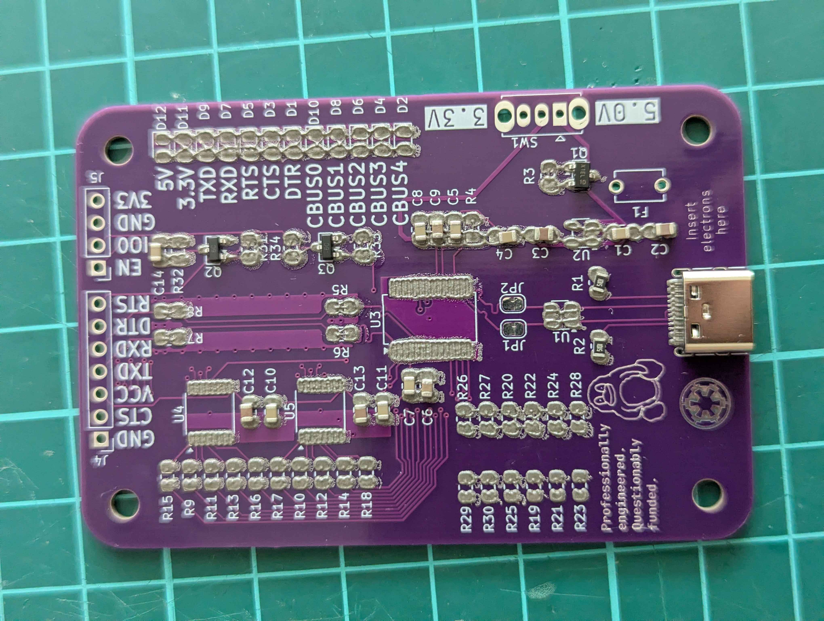
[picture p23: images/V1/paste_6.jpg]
paste mid

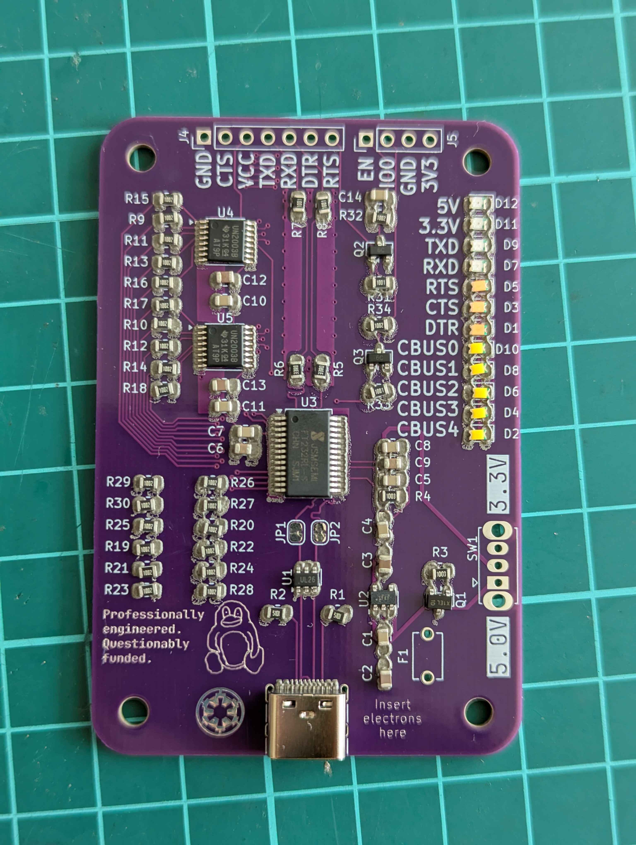
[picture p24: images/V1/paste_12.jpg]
paste done


placed everything while the paste was tacky. got a bridge between two pins on the ssop-28 ft232rl and one on a uln2003 (tssop-16), dragged those out with flux and wick. checked every pin under the magnifying glass after that.

skipped the fuse for now, figured id deal with it later.
powered it up for the first time... nothing caught fire or released magic smoke, so thats a win.

**Total time spent: 4 hours**

# August 22: bring up and testing

first proper test. checked the rails with the multimeter before plugging anything important in - 5v on vbus after where the fuse should be, and 3.3v coming off the ldo nice and stable. both within spec.

did have to do some surgery: never bothered fitting the pptc, just blobbed solder across its pads instead. also cut a trace and jumpered it. not gonna pretend either of those were in the plan.

after all that, plugged into the laptop and it enumerated straight away - lsusb picked it up, no driver drama.

didnt get around to testing the esp auto-reset flashing yet, will do that next session. but the core of the board works which means the schematic wasnt garbage after all.

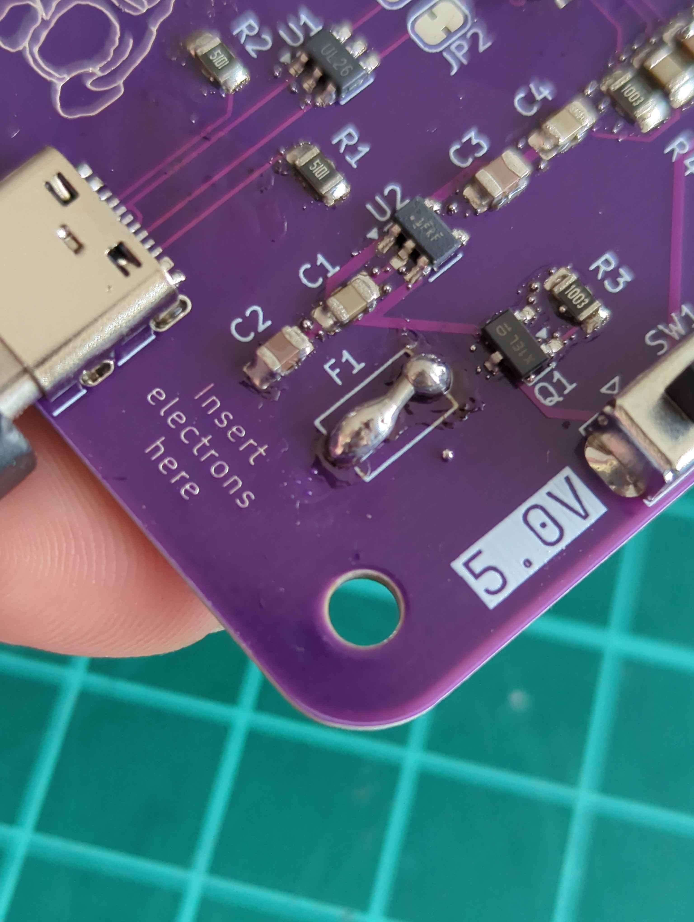
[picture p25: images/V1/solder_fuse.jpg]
fuse bridged

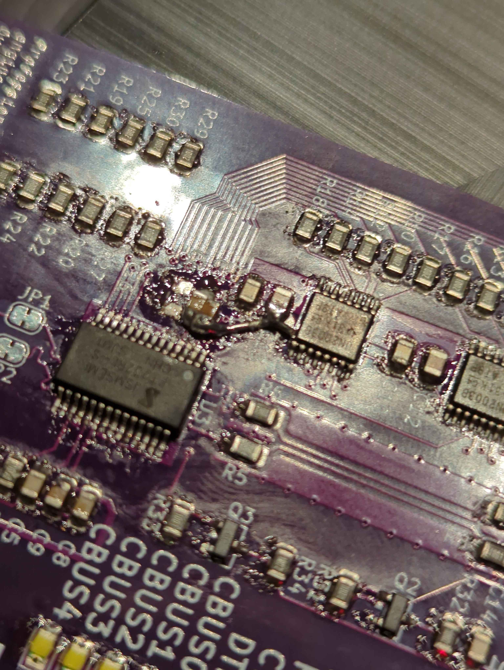
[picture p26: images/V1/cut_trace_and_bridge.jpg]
rework

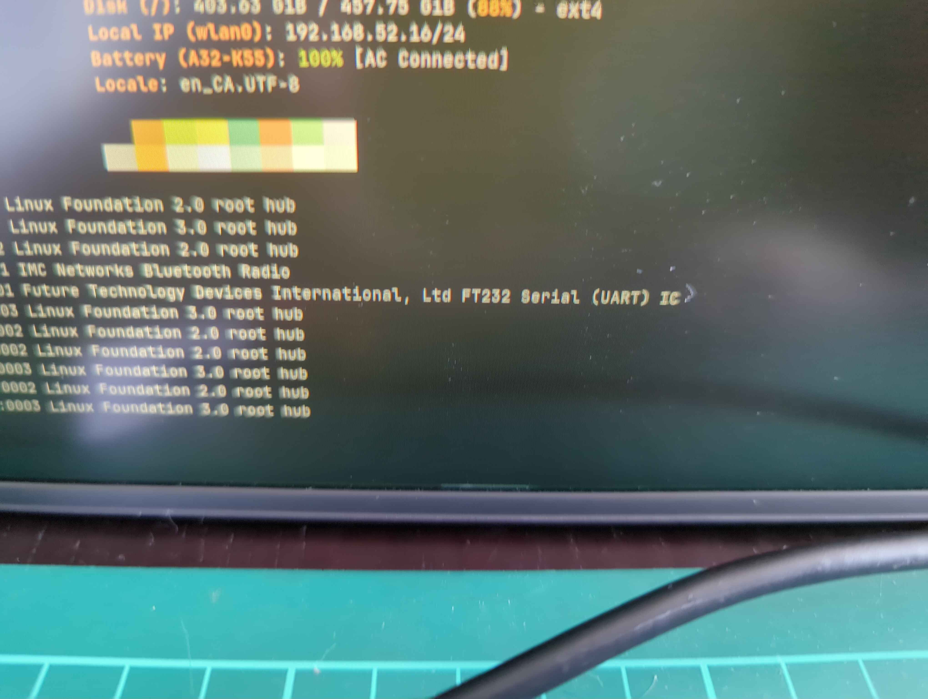
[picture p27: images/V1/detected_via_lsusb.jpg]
lsusb


video of the fuse bridge:
[bridging the fuse](images/V1/bridge_fuse_with_tweezers.mp4)

**Total time spent: 4 hours**

# August 23: proving the board actually works

before trusting the board in a real flash attempt i wanted hard evidence it wasnt garbage.

lsusb picked up the ft232rl straight away - 0403:6001, ftdi_sio bound clean, factory eeprom strings since i never programmed any. loopback test through the header pins passed. then passed AGAIN later mid-session just to be sure. board exonerated twice, feels good.

while poking around i confirmed the vccio bug id suspected - io pins stay at 3.3v even with the switch flipped to 5v, worked fine until you actually use the switch. bodged a wire so vccio follows the switched rail. also caught the auto-reset stage latching: after the first trigger it held enable down until you pulled power. added a bodge resistor so it releases properly.

characterized the power budget while i was in there (idle / leds all lit / data blasting) and dumped todays findings into the grant narrative. honestly the war stories section writes itself.
usb

**Total time spent: 3 hours**

# August 23: the esp32 flashing saga

this ate my whole evening. tried flashing an esp32 devkit through the board and got absolutely nothing on rx.

the confusion spiral was real. passive listen at 115200: silent. baud scan across every rate i know, both dtr/rts polarities: silent. the multimeter showed weak 1-3v swings which turned out to be the dmm averaging square waves. spent ages doubting my wiring labels until a grounding exercise pin by pin proved they were right all along.

built some c probes against libftdi1 to get at the raw pins - pin level sampling, a slow toggle to verify with the meter, live edge monitoring, and async bitbang waveform captures. learned the hard way that every raw libftdi run detaches the kernel driver and never gives it back, so /dev/ttyUSB0 kept vanishing and masquerading as hardware faults. manual sysfs rebinding after every probe. only one genuine bus disconnect the entire night.

then the side quest: the uno i grabbed to test the cable half-enumerated with error -71, zero interfaces. same cable on a different port: clean enum plus a 45 second stress test, 85kb written, zero errors. verdict - the pc usb port is faulty. not the cable, not the board. moved everything to the good port and switched to the sparkfun cable for the rest of the night, it just works.

breakthrough: after swapping wires at the devkit end, the waveform capture showed six dense uart bursts, and a live listen during reset caught the full boot rom text at 115200 - rst:0x1 (POWERON_RESET), boot:0x13 (SPI_FAST_FLASH_BOOT), the whole banner. turns out its an adafruit huzzah32 breakout, no onboard usb-serial and no auto-reset circuit.

endgame: esptool still refuses to connect even with the download-mode banner showing seconds before each try. byte level trace shows valid sync frames going out, 100ms waits, zero response, thirty times over. grounds verified at ~0 ohm, levels safe at 3.3v logic, both jumper wires individually proven conductive, adapter loopback re-passed mid session. even applied the adafruit erratum - pre aug 2020 boards ship missing the 1k rx pull up - added one externally, verified electrically. still nothing. twenty rounds of raw sync patterns later the only catch was another stray boot banner from an accidental reset press.

final verdict: my board fully functional, cable good, port replaced, wiring correct. the esp32 boots and runs fine but uart0-rx seems deaf - can boot existing flash, cant take new flashes over serial. gonna cross check with a borrowed adapter before condemning the chip.

oh and the host logs were spamming pcie correctable errors from the gpu slot all night. platform level electrical noise, worth watching.

viewport

**Total time spent: 5 hours**
# September 2: proving the board actually works

finally did the real tests. not "lsusb says hello" tests, actual bit-level stress proving the board is electrically sound.

started with self-loopback, jumpered tx to rx, 500 blocks of 512 bytes at 115200 baud back to back. 500 out of 500 passed, zero bad bytes! 8.7 kB/s. that was the test. 512 bytes was chosen on purpose because thats exactly the block size that triggers bit flips through the esp32, if the board alone can push 512 bytes clean 500 times in a row, the tx/rx driver is fine. (in theorey)

then did a direct pc loopback (board tx/rx jumpered, driven by the host) - 100x32 byte chunks, 100/100 clean. board + cable + pc port all proven in one shot.

reconnected the esp32 for integration testing. light traffic (16 byte frames with 50ms gaps) passed 20/20. short frames under 64 bytes with even 100us gaps: 100% clean. single bytes: 300/300. the board talks to the esp32 just fine for normal paced uart traffic.

Issues:
- esp auto reset circuit wired incorrectlly
- vio trace too thin for esp32

wrote all the findings into the grant narrative too. real engineering war stories beat smooth sailing every time.

proof

**Total time spent: 4 hours**

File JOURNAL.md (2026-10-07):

---
title: "FTDI Board"
author: pn2222a
description: "FTDI USB board based on FT232RL chip"
created_at: "2026-06-21T02:59:14Z"
---

# September 1: v1.1 redesign

went back to the schematic and cut a bunch of stuff out. the build worked but there was obvious fat to trim.

the uln2003s are gone. i added em back in june as "cheap insurance" for buffering cbus outputs but honestly i never used them for anything and they were just dead weight eating board space and adding eight resistors plus four caps to the bom. open collector drivers sounded cool on paper but the leds and headers work straight off the ft232rl pins fine. deleted u4 and u5 and everything hanging off them.

added a second fuse. f1 on vbus stays as the main overcurrent protection but i put a fine 2.5a 0603 polyfuse downstream of it. idea is one fuse catches gross shorts at the connector and the smaller one protects the actual rails a bit tighter. probably overkill but im clumsy and cheap insurance turned out to not be that cheap last time.

also dropped in a 13th led, one more cbus indicator so every cbus pin is visible now.

renamed the headers j4/j5 to j2/j3 while i was in there, the old numbering was just leftover nonsense from the original layout.

then the killer part - rerouted the whole pcb. placement got a full shuffle which meant redoing most of the traces anyway, and i tidied up the ones that were ugly the first time. kept the 4-layer stackup because the planes make everything simpler. gerbers regenerated and the board file is way cleaner than v1.0.

bonus: the whole netlist got revisited and the board was laid out fresh instead of bolting onto the old routing, so all the weird quirks i found while testing the v1.0 proto got a chance to be done right this time around.

pcb

**Total time spent: 4 hours**

# September 21: v1.1 boards arrived, built

## What I did

- v1.1 pcbs arrived (redesign from september 1 - uln2003s gone, second fuse added, all the fat trimmed)
- assembled the board
- skipped the fuse again, bridged it with tweezers (same as v1.0)
- powered it up

## Why

- wanted to prove the redesign is actually better, not just prettier in the schematic
- leds didnt work on v1

## Screenshots

[bridging the fuse](proof/V1-1/video/VID_20260921_184839.mp4)

once the bridge was in, all the leds lit up and stayed lit - nicest possible first reaction from a board.

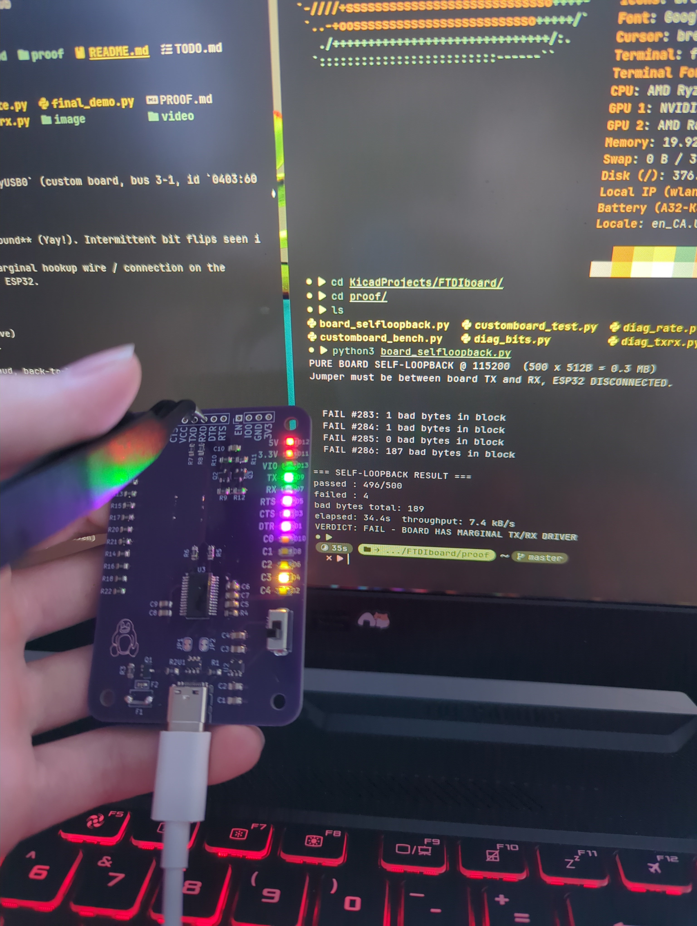
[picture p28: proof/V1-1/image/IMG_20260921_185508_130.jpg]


**Total time spent: 3 hours**

---

# September 21: v1.1 testing

## What I did

- reran the whole proof kit on the v1.1 board - self-loopback, paced esp32 traffic, sustained-load stress
- confirmed the two v1.0 bugbear fixes hold: auto reset stage no longer latches, vccio rail follows the switch
- recorded the test script running

## Why

- v1.0 testing taught me 512-byte back-to-back blocks are the killer for bit flips through the esp32, so i wouldnt trust v1.1 blind
- wanted on-camera proof instead of "trust me it passed"

## Screenshots

[test script running](proof/V1-1/video/VID_20260921_190001.mp4)

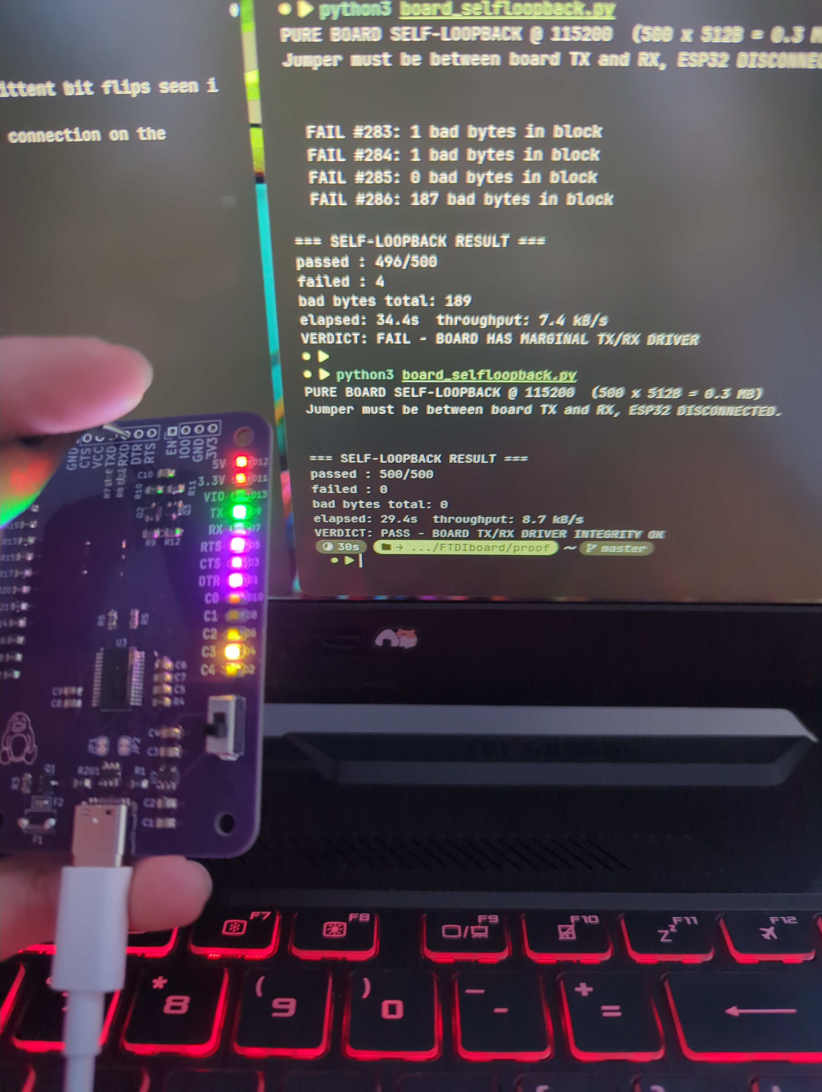
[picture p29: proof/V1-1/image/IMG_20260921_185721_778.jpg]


board sat there doing the full self loopback pass clean. the fixes from the redesign actually fixed things and not just the drawing. v1.1 works.

**Total time spent: 3 hours**

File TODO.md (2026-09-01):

v2:
- [] make power traces thicker
- [] fix bitcoin qr code
- [] fix uln2003 leds
- [] external crystal?
- [] use resistor arrays
- [] smd parts
- [] multiple regulators
- [] ft232rl output voltage

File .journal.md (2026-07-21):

---
title: "FTDI Board"
author: pn2222a
descrriptioni: "FTDI USB board based on FT232RL chip"
created_at: "2026-06-21T02:59:14Z"
---

# June 10: project start and component selection

started the project. needed a usb-to-uart board for flashing esp32 and other mcus.
chose the ft232rl as the main ic since it's well supported and cheap.
added usbLC6 for esd protection on the usb lines.
picked the tlv75733 for 3.3v regulation with a switchable 5v option.
going with usb-c for the connector since it's 2026.
sch power

**Total time spent: 2 hours**

# June 11: schematic - power section

drew out the power section of the schematic.
usb-c connector with cc resistors (5.1k pulldowns for ufp).
esd protection on d+/d-.
pptc fuse for overcurrent protection.
3.3v ldo with input/output caps.
added the voltage selection switch between 3.3v and 5v.
sch power

**Total time spent: 3 hours**

# June 13: schematic - ft232rl core

added the ft232rl and surrounding circuitry.
crystal-less design since ft232rl has internal clock.
decoupling caps on all power pins.
connected the status pins (tx, rx, rts, cts, dtr, dsr, dcd, ri) to led indicators.
added the auto-reset circuit for esp-style programming with npn transistors on dtr and rts.
sch core

**Total time spent: 4 hours**

# June 14: schematic - leds and connectors

finished the led indicator section. 12 leds total for all the status signals.
added the 2x pin headers - 1x7 for main uart signals and 1x4 for extra gpio/cbus.
all 0805 package for easy hand soldering.
did a final review of the full schematic, caught a few net naming issues.
sch leds

**Total time spent: 3 hours**

# June 16: initial pcb layout

imported the netlist and placed all components.
kept the usb connector on one edge and headers on the opposite.
grouped bypass caps near the ft232rl.
board is 75x50mm with m3 mounting holes in the corners.
started with a 4-layer stackup - signal/gnd/power/signal.
pcb placement

**Total time spent: 4 hours**

# June 17: pcb routing

started routing. power traces are 0.5mm, signal traces 0.2mm.
used inner layers for ground and 3.3v planes to keep routing clean.
routed the usb differential pair with matched lengths.
added copper pours for ground on both outer layers.
pcb routing

**Total time spent: 5 hours**

# June 18: pcb routing continued

finished routing all the signal traces.
connected all the led indicators through current limiting resistors.
added thermal relief pads to the power plane connections.
ran drc and fixed a few clearance violations near the usb connector.
pcb routing2

**Total time spent: 4 hours**

# June 19: final pcb touches

added silkscreen labels for all connectors and key components.
put the project name and version on the board.
added a moon graphic on the silkscreen as a little easter egg.
did final drc check - all passed.
pcb final

**Total time spent: 3 hours**

# June 20: finished board

finished the board.
added moon silkscreen and some more easter eggs, even though it will probably be only me that uses it
pcb

**Total time spent: 6 hours**

# June 21: polishing repo
adding images from kicad and will start blendering soon for some cool renders
i need to learn how to make the renders faster.
sch

**Total time spent: 2 hours**

# June 23: Blender
started blender model for pcb
red solder mask, white silkscreen, enig finish
render

**Total time spent: 3 hours**

# June 24: polish readme
adding images to readme and make bom.csv draft for parts and whatnot
will make more blender renders soon with animations and effects
sch

**Total time spent: 3 hours**

# June 25: BOM
looked for parts and made a bom
parts are from lcsc
added pcbs from jlcpcb and pcbway just in case
the more the merrier they say
sch

**Total time spent: 4 hours**

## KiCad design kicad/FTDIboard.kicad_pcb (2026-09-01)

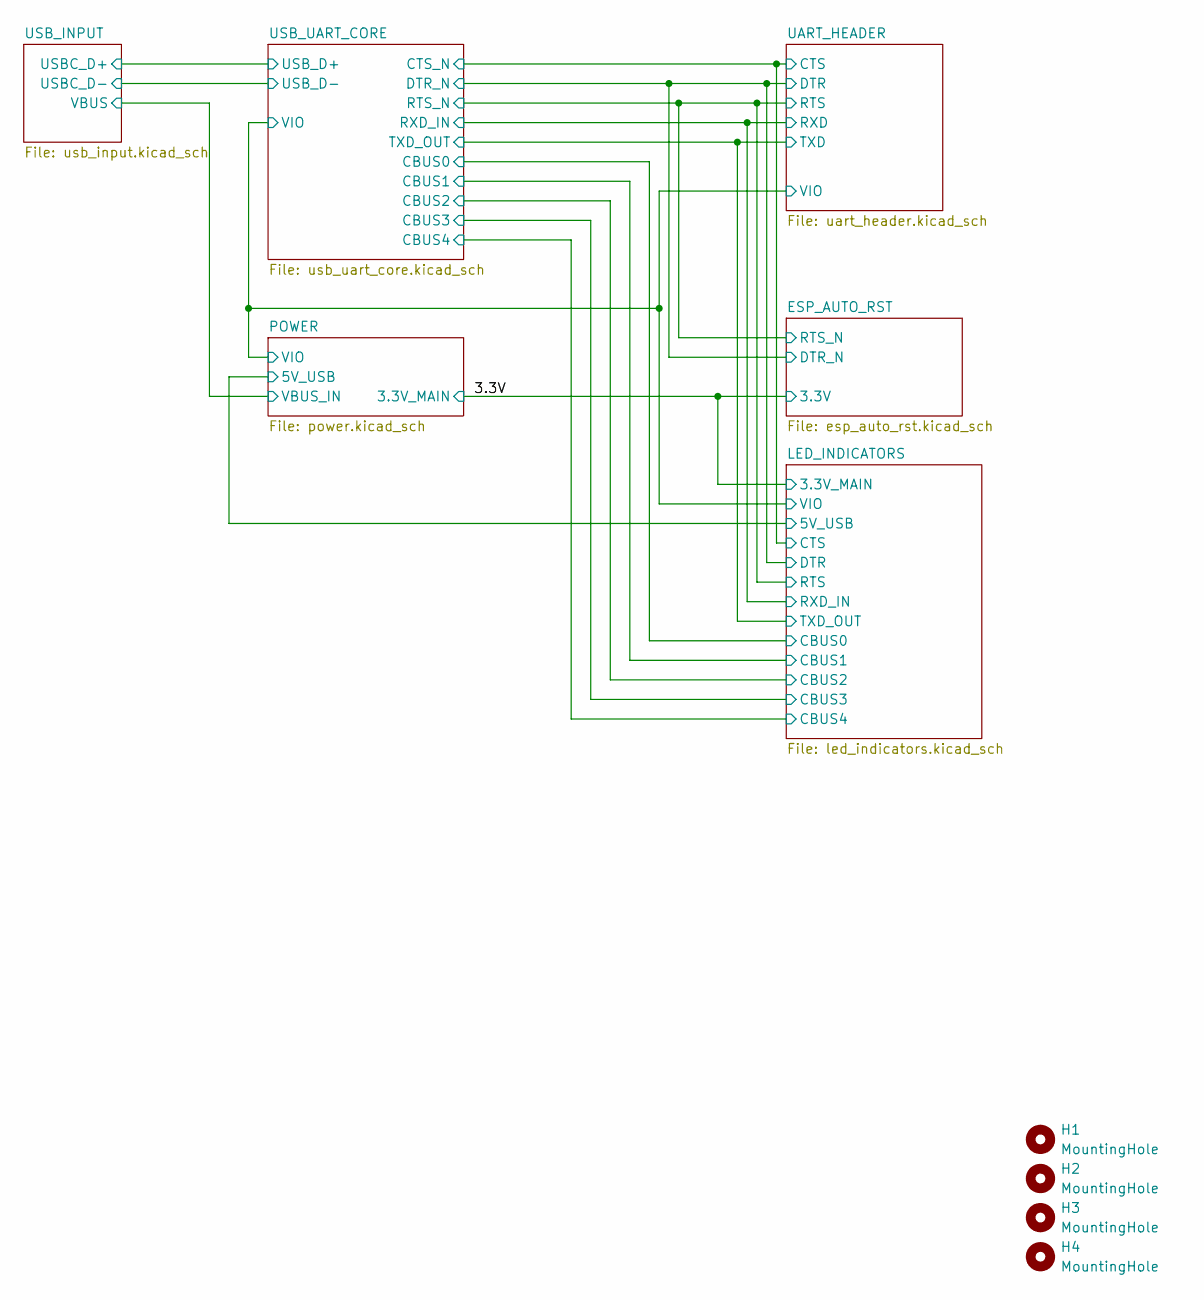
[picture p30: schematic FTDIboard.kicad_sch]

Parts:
H1, H2, H3, H4: MountingHole; MountingHole_3.2mm_M3

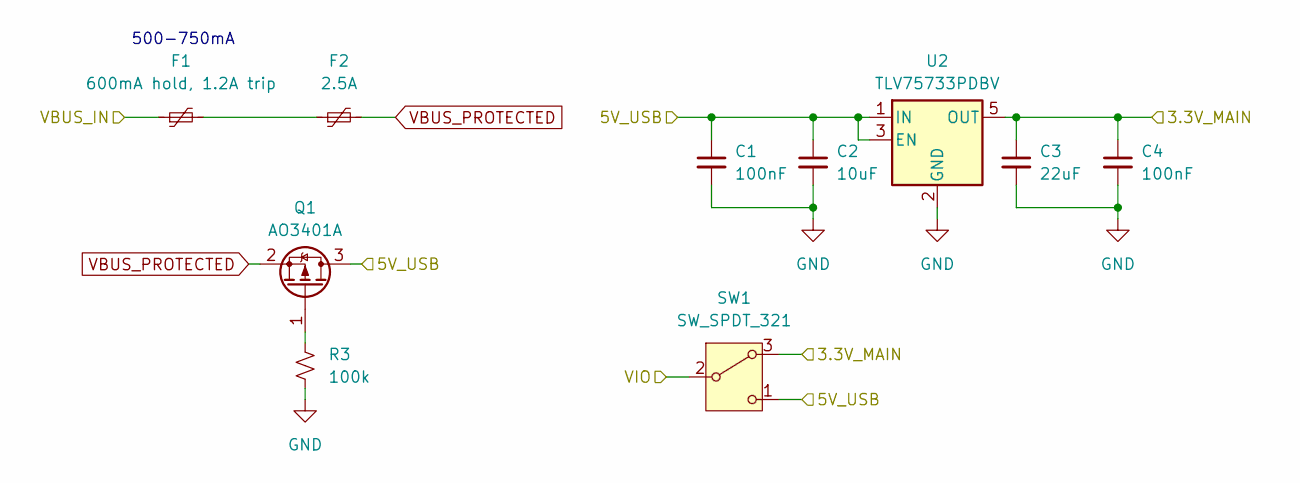
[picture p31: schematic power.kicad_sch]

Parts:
C1, C4: 100nF; C_0805_2012Metric_Pad1.18x1.45mm_HandSolder
C2: 10uF; C_0805_2012Metric_Pad1.18x1.45mm_HandSolder
C3: 22uF; C_0805_2012Metric_Pad1.18x1.45mm_HandSolder
F1: 600mA hold, 1.2A trip; C_Disc_D5.1mm_W3.2mm_P5.00mm
F2: 2.5A; Fuse_0603_1608Metric
Q1: AO3401A; SOT-23
R3: 100k; R_0805_2012Metric_Pad1.20x1.40mm_HandSolder
SW1: SW_SPDT_321; SW_Slide_SPDT_Straight_CK_OS102011MS2Q
U2: TLV75733PDBV; SOT-23-5

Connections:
/3.3V: C3.1, C4.1, SW1.3 (A), U2.5 (OUT); also elsewhere on the board
/LED_INDICATORS/5V_USB: C1.1, C2.1, Q1.3 (D), SW1.1 (C), U2.1 (IN), U2.3 (EN); also elsewhere on the board
/LED_INDICATORS/VIO: SW1.2 (B); also elsewhere on the board
/POWER/VBUS_IN: F1.1; also elsewhere on the board
GND: C1.2, C2.2, C3.2, C4.2, R3.2, U2.2 (GND); also elsewhere on the board
unnamed: F1.2, F2.1
unnamed: Q1.1 (G), R3.1
VBUS_PROTECTED: F2.2, Q1.2 (S)

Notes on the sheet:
500-750mA

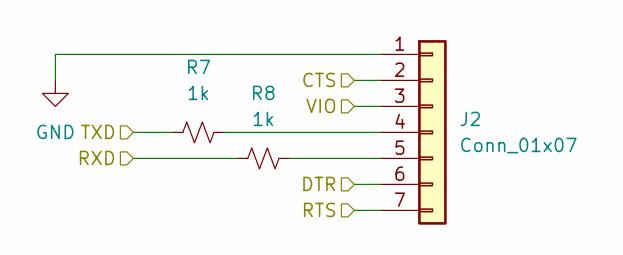
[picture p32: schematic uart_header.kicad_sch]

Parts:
J2: Conn_01x07; PinHeader_1x07_P2.54mm_Vertical
R7, R8: 1k; R_0805_2012Metric_Pad1.20x1.40mm_HandSolder

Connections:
/ESP_AUTO_RST/DTR_N: J2.6; also elsewhere on the board
/ESP_AUTO_RST/RTS_N: J2.7; also elsewhere on the board
/LED_INDICATORS/CTS: J2.2; also elsewhere on the board
/LED_INDICATORS/RXD_IN: R8.1; also elsewhere on the board
/LED_INDICATORS/TXD_OUT: R7.1; also elsewhere on the board
/LED_INDICATORS/VIO: J2.3; also elsewhere on the board
GND: J2.1; also elsewhere on the board
unnamed: J2.4, R7.2
unnamed: J2.5, R8.2

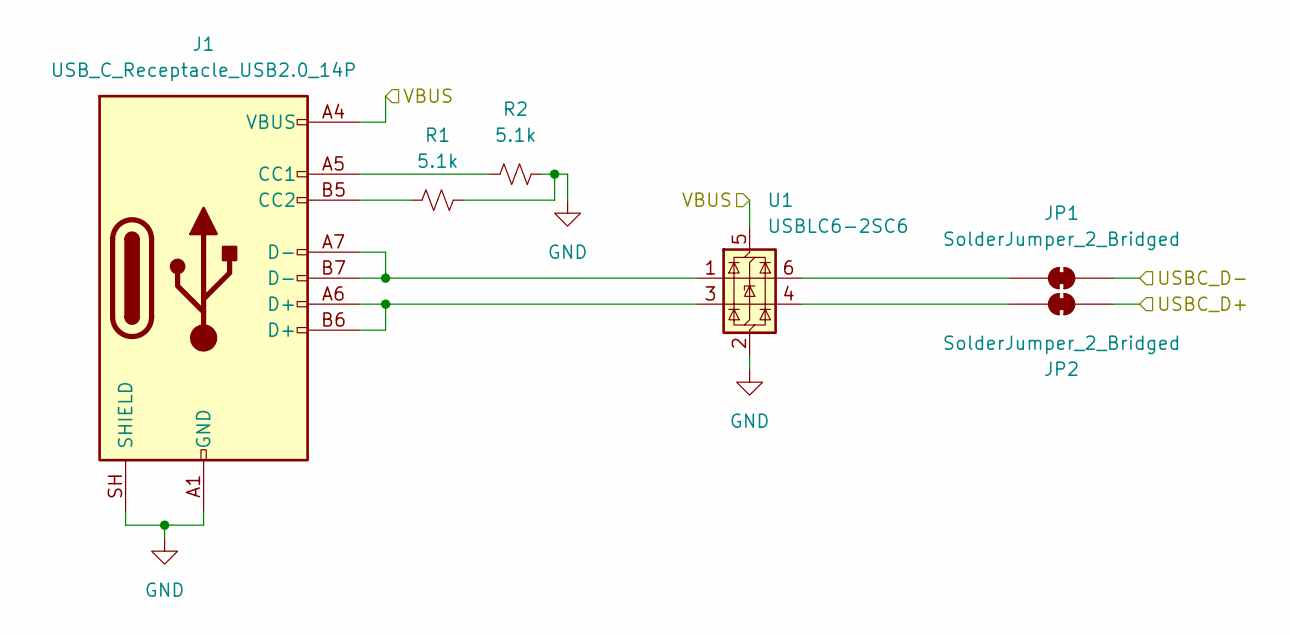
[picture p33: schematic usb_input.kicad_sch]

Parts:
J1: USB_C_Receptacle_USB2.0_14P; USB_C_Receptacle_HRO_TYPE-C-31-M-12
JP1, JP2: SolderJumper_2_Bridged; SolderJumper-2_P1.3mm_Bridged_RoundedPad1.0x1.5mm
R1, R2: 5.1k; R_0805_2012Metric_Pad1.20x1.40mm_HandSolder
U1: USBLC6-2SC6; SOT-23-6

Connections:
/POWER/VBUS_IN: J1.A4 (VBUS), J1.A9 (VBUS), J1.B4 (VBUS), J1.B9 (VBUS), U1.5 (VBUS); also elsewhere on the board
/USB_INPUT/USBC_D+: JP2.1 (A); also elsewhere on the board
/USB_INPUT/USBC_D-: JP1.2 (B); also elsewhere on the board
GND: J1.A1 (GND), J1.A12 (GND), J1.B1 (GND), J1.B12 (GND), J1.SH (SHIELD), R1.2, R2.2, U1.2 (GND); also elsewhere on the board
unnamed: J1.A5 (CC1), R2.1
unnamed: J1.B5 (CC2), R1.1
unnamed: J1.A6 (D+), J1.B6 (D+), U1.3 (I/O2)
unnamed: J1.A7 (D-), J1.B7 (D-), U1.1 (I/O1)
unnamed: JP1.1 (A), U1.6 (I/O1)
unnamed: JP2.2 (B), U1.4 (I/O2)

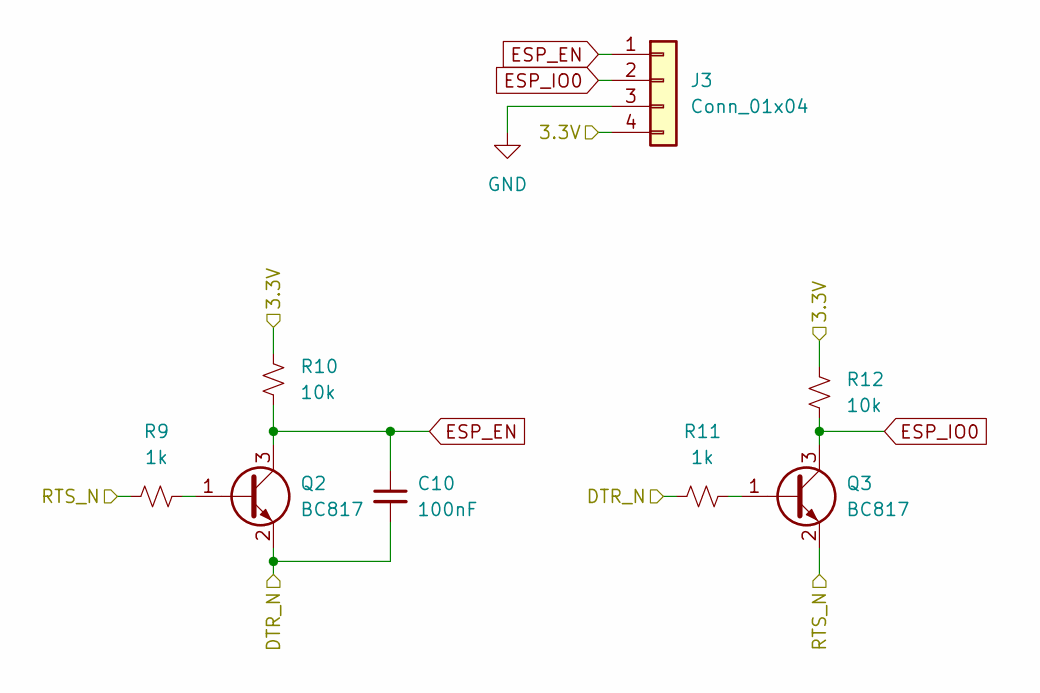
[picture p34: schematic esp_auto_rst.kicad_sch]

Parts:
C10: 100nF; C_0805_2012Metric_Pad1.18x1.45mm_HandSolder
J3: Conn_01x04; PinHeader_1x04_P2.54mm_Vertical
Q2, Q3: BC817; SOT-23
R9, R11: 1k; R_0805_2012Metric_Pad1.20x1.40mm_HandSolder
R10, R12: 10k; R_0805_2012Metric_Pad1.20x1.40mm_HandSolder

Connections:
/3.3V: J3.4, R10.1, R12.1; also elsewhere on the board
/ESP_AUTO_RST/DTR_N: C10.2, Q2.2 (E), R11.1; also elsewhere on the board
/ESP_AUTO_RST/RTS_N: Q3.2 (E), R9.1; also elsewhere on the board
ESP_EN: C10.1, J3.1, Q2.3 (C), R10.2
ESP_IO0: J3.2, Q3.3 (C), R12.2
GND: J3.3; also elsewhere on the board
unnamed: Q2.1 (B), R9.2
unnamed: Q3.1 (B), R11.2

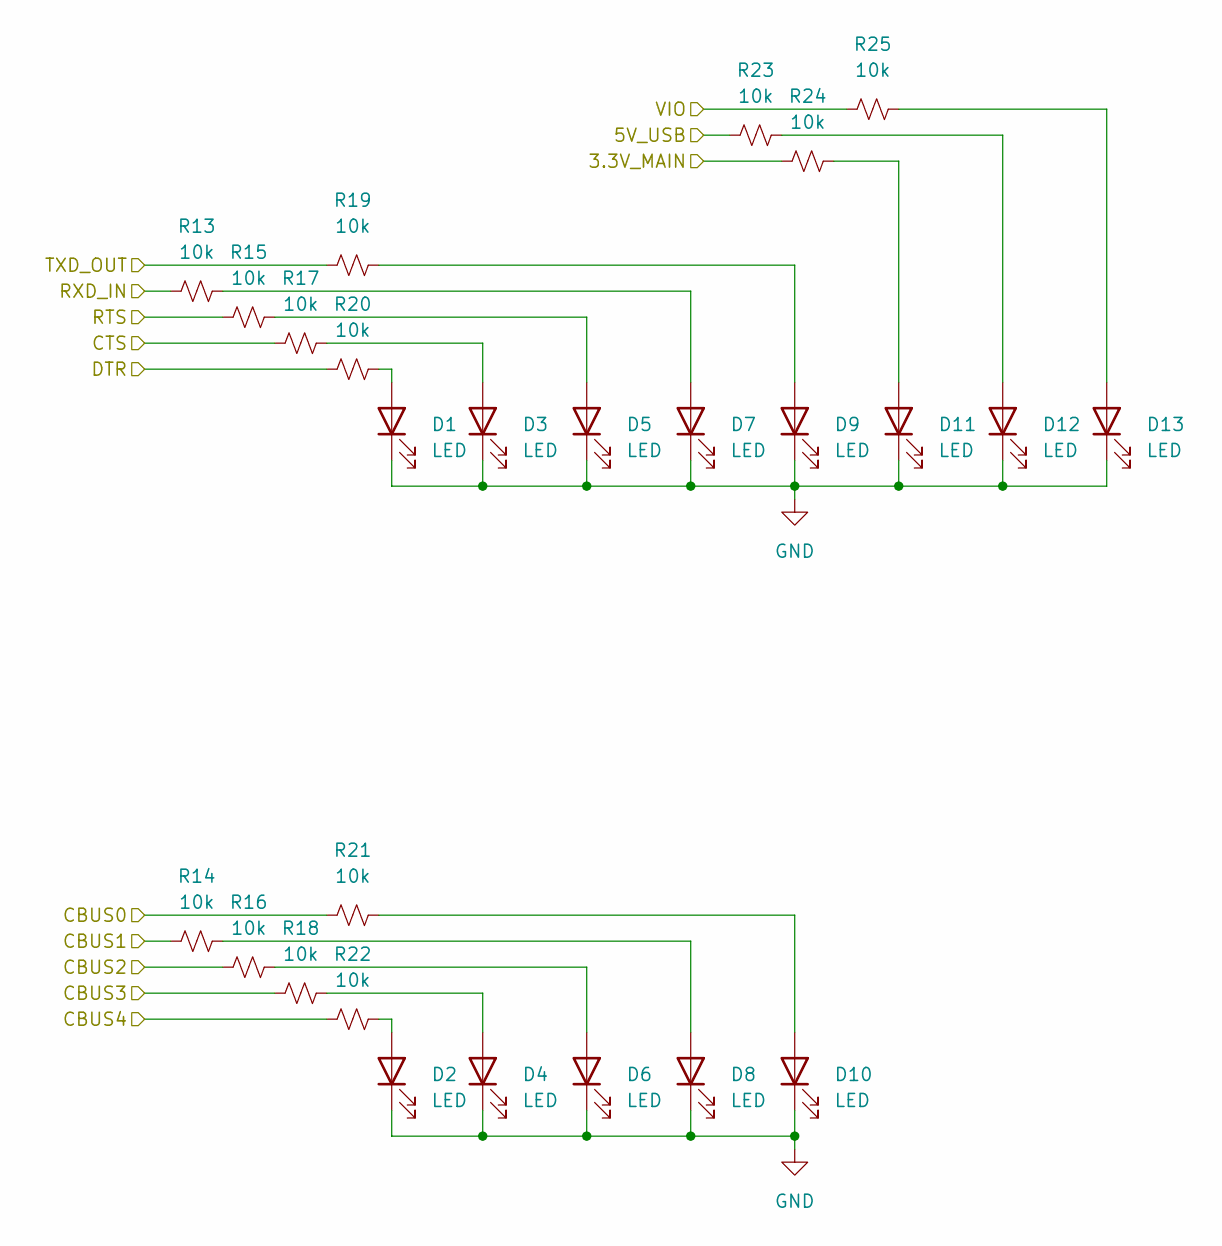
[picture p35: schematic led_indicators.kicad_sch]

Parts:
D1, D2, D3, D4, D5, D6, D7, D8, D9, D10, D11, D12, D13: LED; LED_0805_2012Metric_Pad1.15x1.40mm_HandSolder
R13, R14, R15, R16, R17, R18, R19, R20, R21, R22, R23, R24, R25: 10k; R_0805_2012Metric_Pad1.20x1.40mm_HandSolder

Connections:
/3.3V: R24.1; also elsewhere on the board
/ESP_AUTO_RST/DTR_N: R20.1; also elsewhere on the board
/ESP_AUTO_RST/RTS_N: R15.1; also elsewhere on the board
/LED_INDICATORS/5V_USB: R23.1; also elsewhere on the board
/LED_INDICATORS/CBUS0: R21.1; also elsewhere on the board
/LED_INDICATORS/CBUS1: R14.1; also elsewhere on the board
/LED_INDICATORS/CBUS2: R16.1; also elsewhere on the board
/LED_INDICATORS/CBUS3: R18.1; also elsewhere on the board
/LED_INDICATORS/CBUS4: R22.1; also elsewhere on the board
/LED_INDICATORS/CTS: R17.1; also elsewhere on the board
/LED_INDICATORS/RXD_IN: R13.1; also elsewhere on the board
/LED_INDICATORS/TXD_OUT: R19.1; also elsewhere on the board
/LED_INDICATORS/VIO: R25.1; also elsewhere on the board
GND: D1.1 (K), D2.1 (K), D3.1 (K), D4.1 (K), D5.1 (K), D6.1 (K), D7.1 (K), D8.1 (K), D9.1 (K), D10.1 (K), D11.1 (K), D12.1 (K), D13.1 (K); also elsewhere on the board
unnamed: D1.2 (A), R20.2
unnamed: D2.2 (A), R22.2
unnamed: D3.2 (A), R17.2
unnamed: D4.2 (A), R18.2
unnamed: D5.2 (A), R15.2
unnamed: D6.2 (A), R16.2
unnamed: D7.2 (A), R13.2
unnamed: D8.2 (A), R14.2
unnamed: D9.2 (A), R19.2
unnamed: D10.2 (A), R21.2
unnamed: D11.2 (A), R24.2
unnamed: D12.2 (A), R23.2
unnamed: D13.2 (A), R25.2

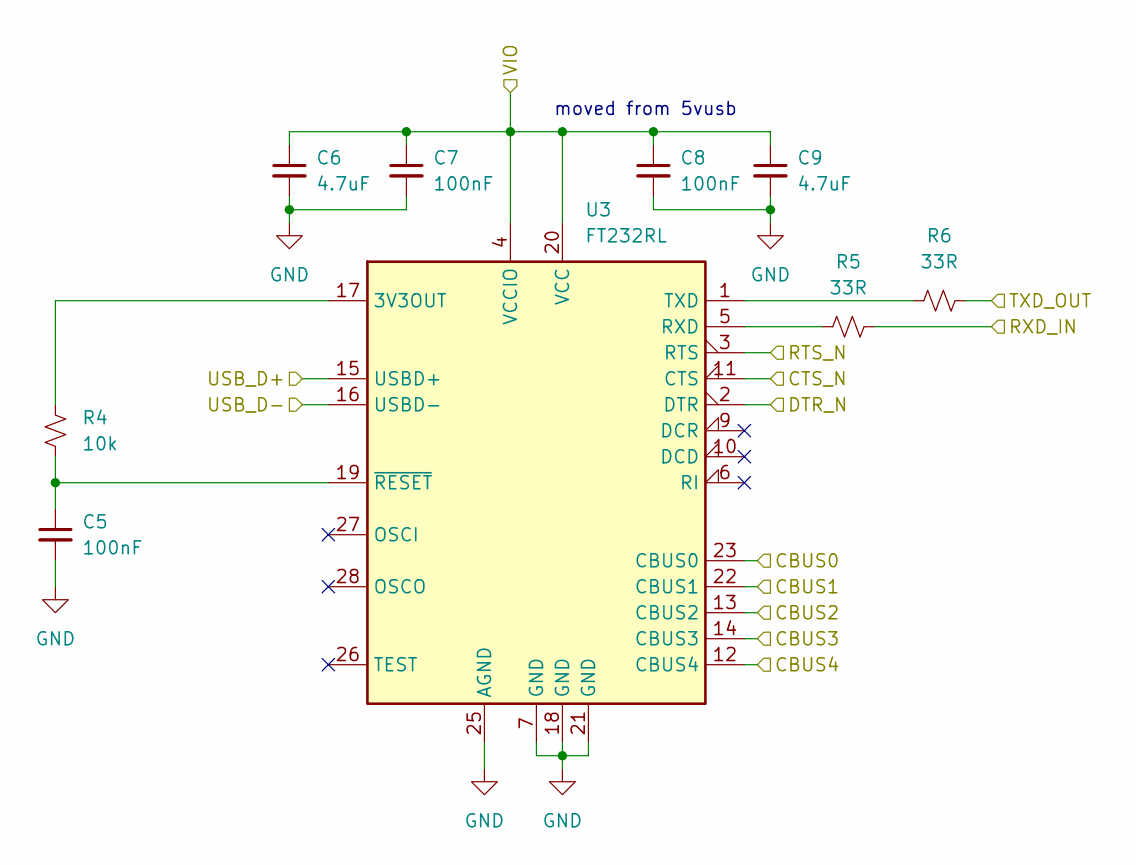
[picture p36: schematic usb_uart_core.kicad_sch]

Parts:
C5, C7, C8: 100nF; C_0805_2012Metric_Pad1.18x1.45mm_HandSolder
C6, C9: 4.7uF; C_0805_2012Metric_Pad1.18x1.45mm_HandSolder
R4: 10k; R_0805_2012Metric_Pad1.20x1.40mm_HandSolder
R5, R6: 33R; R_0805_2012Metric_Pad1.20x1.40mm_HandSolder
U3: FT232RL; SSOP-28_5.3x10.2mm_P0.65mm

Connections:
/ESP_AUTO_RST/DTR_N: U3.2 (DTR); also elsewhere on the board
/ESP_AUTO_RST/RTS_N: U3.3 (RTS); also elsewhere on the board
/LED_INDICATORS/CBUS0: U3.23 (CBUS0); also elsewhere on the board
/LED_INDICATORS/CBUS1: U3.22 (CBUS1); also elsewhere on the board
/LED_INDICATORS/CBUS2: U3.13 (CBUS2); also elsewhere on the board
/LED_INDICATORS/CBUS3: U3.14 (CBUS3); also elsewhere on the board
/LED_INDICATORS/CBUS4: U3.12 (CBUS4); also elsewhere on the board
/LED_INDICATORS/CTS: U3.11 (CTS); also elsewhere on the board
/LED_INDICATORS/RXD_IN: R5.2; also elsewhere on the board
/LED_INDICATORS/TXD_OUT: R6.2; also elsewhere on the board
/LED_INDICATORS/VIO: C6.1, C7.1, C8.1, C9.1, U3.4 (VCCIO), U3.20 (VCC); also elsewhere on the board
/USB_INPUT/USBC_D+: U3.15 (USBD+); also elsewhere on the board
/USB_INPUT/USBC_D-: U3.16 (USBD-); also elsewhere on the board
GND: C5.2, C6.2, C7.2, C8.2, C9.2, U3.7 (GND), U3.18 (GND), U3.21 (GND), U3.25 (AGND); also elsewhere on the board
unnamed: R4.1, U3.17 (3V3OUT)
unnamed: R5.1, U3.5 (RXD)
unnamed: R6.1, U3.1 (TXD)
unnamed: C5.1, R4.2, U3.19 (~RESET)

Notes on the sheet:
moved from 5vusb

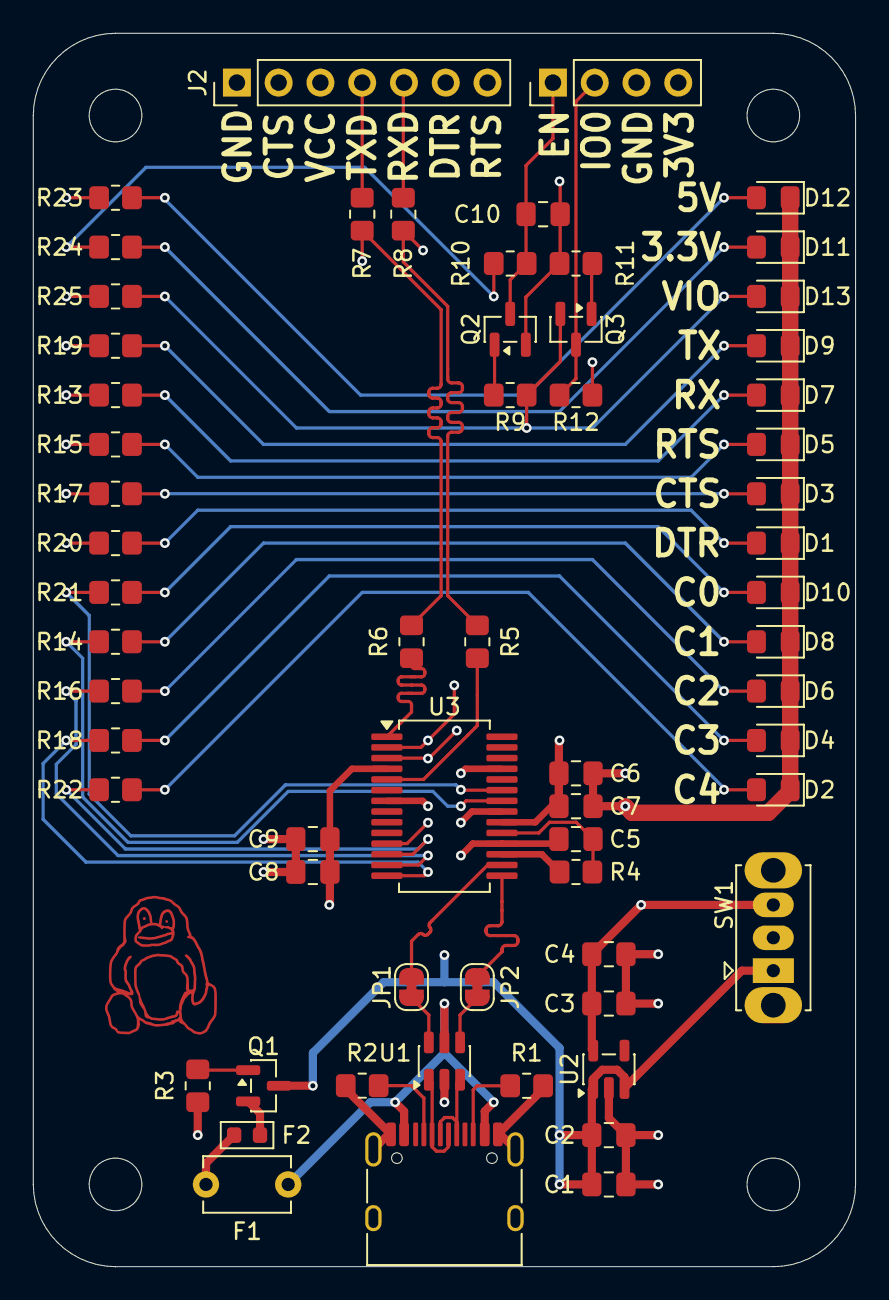
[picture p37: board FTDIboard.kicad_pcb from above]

Board: 4 copper layers, 50.0 x 75.0 mm, 66 parts (0 on the bottom side), 49 nets.

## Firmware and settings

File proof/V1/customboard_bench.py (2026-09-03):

#!/usr/bin/env python3
"""
Custom FT232RL board <-> ESP32 (UART2 RX=19 / TX=21) reliability + throughput benchmark.

Funnels checksum-verified data through:  custom board TX -> ESP32 RX(19)
                                         custom board RX <- ESP32 TX(21)
Requires ZERO byte errors. Reports effective throughput and error rate.
"""
import serial, time, random, hashlib, sys

PORT = '/dev/ttyUSB0'
BAUD = 115200
BLOCK = 512            # bytes per write
ROUNDS = 2000          # blocks -> ~1 MB total
TIMEOUT = 5.0

random.seed(42)
rng = random.Random(42)

def main():
    print(f"Custom FT232RL <-> ESP32 echo benchmark @ {BAUD} baud", flush=True)
    print(f"Pin map: custom TX -> GPIO19, custom RX <- GPIO21", flush=True)
    print(f"Total payload: {BLOCK*ROUNDS/1e6:.1f} MB  ({ROUNDS} x {BLOCK}B blocks)\n", flush=True)

    ser = serial.Serial(PORT, BAUD, timeout=1)
    time.sleep(0.5)
    ser.reset_input_buffer()

    ok = 0
    mismatch = 0
    data_bytes = 0
    t_start = time.time()
    send_start = None
    for i in range(ROUNDS):
        payload = rng.randbytes(BLOCK)
        digest = hashlib.sha256(payload).hexdigest()[:12]
        ser.reset_input_buffer()
        ser.write(payload)
        if send_start is None:
            send_start = time.time()  # start timing once pipe is primed
        got = b''
        t0 = time.time()
        while len(got) < BLOCK and time.time() - t0 < TIMEOUT:
            chunk = ser.read(BLOCK - len(got))
            if not chunk:
                break
            got += chunk
        if len(got) != BLOCK:
            print(f"  TIMEOUT #{i}: got {len(got)}/{BLOCK} bytes", flush=True)
            mismatch += 1
            continue
        data_bytes += BLOCK
        if hashlib.sha256(got).hexdigest()[:12] == digest:
            ok += 1
        else:
            mismatch += 1
            print(f"  CHECKSUM MISMATCH #{i}", flush=True)
        if (i + 1) % 250 == 0:
            elapsed = time.time() - t_start
            rate = (BLOCK * (i + 1)) / max(elapsed, 1e-6)
            print(f"  {i+1}/{ROUNDS} blocks | {rate/1000:.0f} kB/s live", flush=True)

    elapsed = time.time() - t_start
    good_bytes = ok * BLOCK
    overall_rate = good_bytes / elapsed

    print("\n=== RESULTS ===", flush=True)
    print(f"Blocks verified correct : {ok}/{ROUNDS}", flush=True)
    print(f"Errors                  : {mismatch}", flush=True)
    print(f"Bytes verified          : {good_bytes/1e6:.2f} MB", flush=True)
    print(f"Elapsed                 : {elapsed:.2f} s", flush=True)
    print(f"Effective throughput    : {overall_rate/1000:.1f} kB/s", flush=True)
    print(f"Error rate              : {mismatch/ROUNDS:.6%}", flush=True)
    verdict = "PASS" if ok == ROUNDS else "FAIL"
    print(f"VERDICT                 : {verdict}", flush=True)
    ser.close()
    sys.exit(0 if verdict == "PASS" else 1)

if __name__ == "__main__":
    main()

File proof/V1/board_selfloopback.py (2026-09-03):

#!/usr/bin/env python3
"""
Pure custom FT232RL board self-loopback stress(test).

Jumper the board TX <-> RX (NO ESP32 in the path). Sends 512-byte blocks,
identical to the size that failed through the ESP32. If this passes clean,
the board itself is fine and the earlier fault was in the wires to the ESP.
If it fails, the board's TX/RX driver has a real signal-integrity problem.
"""
import serial, time, random, sys

PORT = '/dev/ttyUSB0'
BAUD = 115200
BLOCK = 512
ROUNDS = 500
rng = random.Random(2024)

print(f"PURE BOARD SELF-LOOPBACK @ {BAUD}  ({ROUNDS} x {BLOCK}B = {ROUNDS*BLOCK/1e6:.1f} MB)", flush=True)
print("Jumper must be between board TX and RX, ESP32 DISCONNECTED.\n", flush=True)

ser = serial.Serial(PORT, BAUD, timeout=1)
time.sleep(0.5)
ser.reset_input_buffer()

ok = 0; fail = 0; flips = 0
t0 = time.time()
for i in range(ROUNDS):
    payload = rng.randbytes(BLOCK)
    ser.reset_input_buffer()
    ser.write(payload)
    got = b''
    tt = time.time()
    while len(got) < BLOCK and time.time()-tt < 5:
        c = ser.read(BLOCK-len(got))
        if not c: break
        got += c
    if got == payload:
        ok += 1
    else:
        fail += 1
        nbad = sum(1 for a,b in zip(payload,got) if a!=b)
        flips += nbad
        if fail <= 10 or nbad > 3:
            print(f"  FAIL #{i}: {nbad} bad bytes in block", flush=True)
elapsed = time.time()-t0
rate = (ok+fail)*BLOCK/elapsed
print(f"\n=== SELF-LOOPBACK RESULT ===", flush=True)
print(f"passed : {ok}/{ROUNDS}", flush=True)
print(f"failed : {fail}", flush=True)
print(f"bad bytes total: {flips}", flush=True)
print(f"elapsed: {elapsed:.1f}s  throughput: {rate/1000:.1f} kB/s", flush=True)
verdict = "PASS - BOARD TX/RX DRIVER INTEGRITY OK" if ok==ROUNDS else "FAIL - BOARD HAS MARGINAL TX/RX DRIVER"
print(f"VERDICT: {verdict}", flush=True)
ser.close()
sys.exit(0 if ok==ROUNDS else 1)

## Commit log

2026-06-24 blender updates!
    [FTDIboard.blend]
2026-06-24 bom updates
    [BOM.csv]
2026-06-24 fix gitignore to include schematics
    [FTDIboard.kicad_sch, esp_auto_rst.kicad_sch, led_indicators.kicad_sch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]
2026-06-24 fix images
    [FTDIboard.blend]
2026-06-24 blender upates
    [FTDIboard.blend]
2026-06-25 update bom
2026-06-25 bom update
    [BOM.csv]
2026-06-25 add pcbway stuff
    [bom.csv, designators.csv, positions.csv]
2026-06-25 add jlcpcb
    [bom.csv, designators.csv, positions.csv]
2026-06-25 add pcbs to bom and notes
    [BOM.csv]
2026-07-21 add pcb to bom
    [BOM.csv]
2026-08-06 fix small silkscreen problem
    [FTDIboard.kicad_pcb]
2026-08-06 make new bom and update pcb
    [BOM.csv, bom.csv, designators.csv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]
2026-08-23 journal and todo
    [esp_auto_rst.kicad_sch]
